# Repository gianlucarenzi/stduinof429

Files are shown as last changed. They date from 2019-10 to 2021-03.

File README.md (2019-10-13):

# STDuinoF429
=====================================

First attempt to have an ARDUINO (STM32 Based) Board for usage in 8-bit micros
like Atari 400/800/800XL/130XE and Commodore 64

# Rendered Images
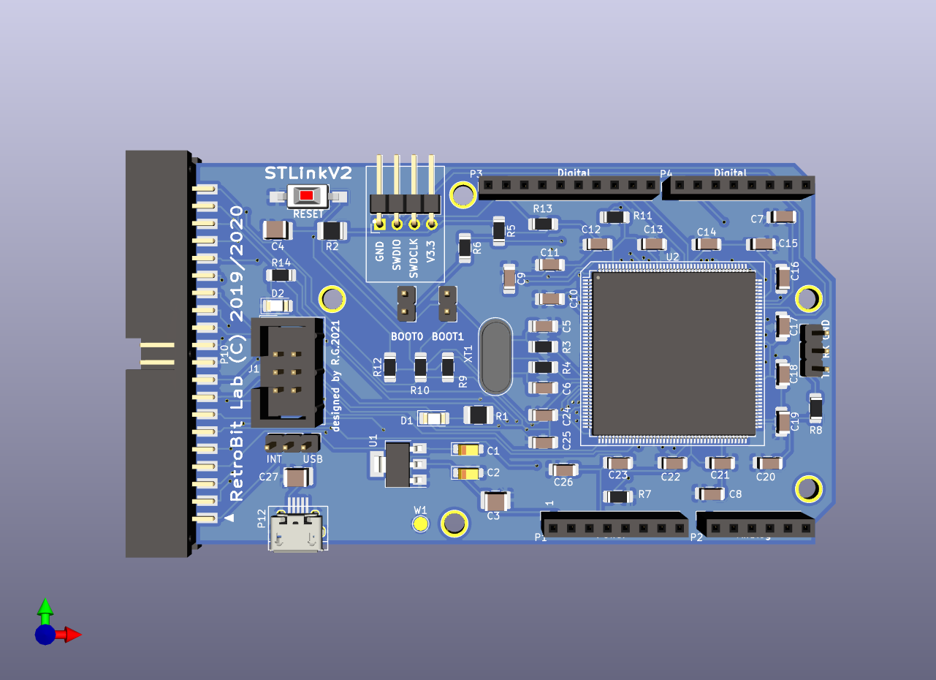
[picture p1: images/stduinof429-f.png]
Board Front
# 
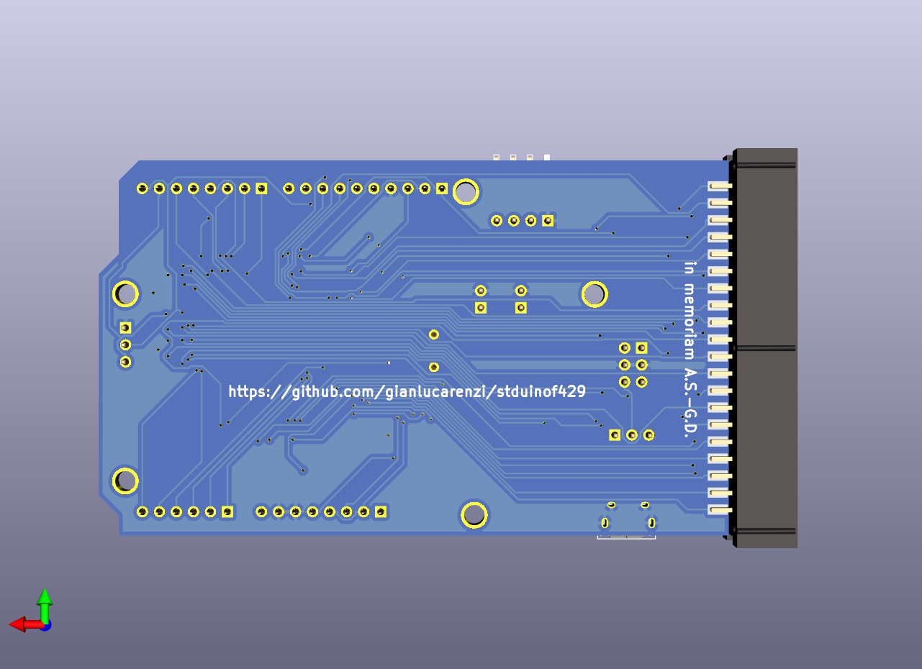
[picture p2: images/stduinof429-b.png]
Board Back
# 
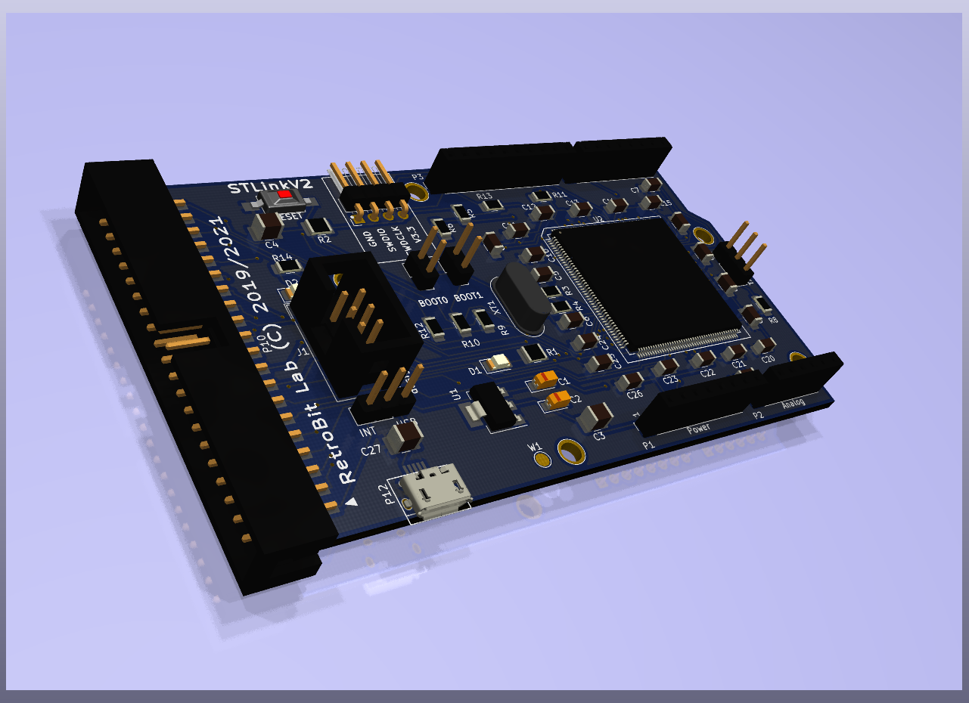
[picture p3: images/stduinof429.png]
Board Overall
# 

Hardware License
---------------------------
Copyright (C) 2018/2019 Gianluca Renzi <gianlucarenzi@eurek.it> <icjtqr@gmail.com>

The hardware of this project is released as free/open hardware under the
GNU GPL v3 License terms. See LICENSE for details.

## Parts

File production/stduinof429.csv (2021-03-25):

Id | Designator | Package | Quantity | Designation | Supplier and ref
1 | P10 | IDC_02X20_2.54mm_Horizontal_PCB_2SIDES | 1 | Conn_02x20_Odd_Even
2 | XT1 | Crystal_HC49-4H_Vertical_3D | 1 | 8Mhz
3 | SW1 | SW_SPST_FSMSM_3D | 1 | SW_PUSH
4 | P12 | USB_Micro-B_Large_Pads | 1 | USB_OTG
5 | J1 | IDC-Header_2x03_P2.54mm_Vertical | 1 | Conn_02x03_Odd_Even
6 | U1 | SOT-223 | 1 | AZ1117-3.3
7 | C7,C8 | C_1206_3216Metric_Pad1.42x1.75mm_HandSolder | 2 | 2.2u
8 | C21,C11,C12,C13,C14,C15,C16,C17,C18,C19,C9,C26,C25,C24,C23,C22,C20 | C_1206_3216Metric_Pad1.42x1.75mm_HandSolder | 17 | 100n
9 | C6,C5 | C_1206_3216Metric_Pad1.42x1.75mm_HandSolder | 2 | 20p
10 | C10 | C_1206_3216Metric_Pad1.42x1.75mm_HandSolder | 1 | 1u
11 | C3,C4,C27 | C_1210_3225Metric_Pad1.42x2.65mm_HandSolder | 3 | 100n
12 | C2 | CP_EIA-3216-18_Kemet-A_Pad1.58x1.35mm_HandSolder | 1 | 22u
13 | C1 | CP_EIA-3216-18_Kemet-A_Pad1.58x1.35mm_HandSolder | 1 | 10u
14 | BOOT0_MEM1,BOOT1_MEM1 | PinHeader_1x02_P2.54mm_Vertical | 2 | CONN_01X02
15 | DEBUG1,P11 | PinHeader_1x03_P2.54mm_Vertical | 2 | CONN_01X03
16 | SWDIO/CLK1 | PinHeader_1x04_P2.54mm_Horizontal | 1 | CONN_01X04
17 | P2 | PinSocket_1x06_P2.54mm_Vertical | 1 | Analog
18 | P1 | PinSocket_1x08_P2.54mm_Vertical | 1 | Power
19 | P4 | PinSocket_1x08_P2.54mm_Vertical | 1 | Digital
20 | P3 | PinSocket_1x10_P2.54mm_Vertical | 1 | Digital
21 | D2 | LED_1206_3216Metric_Pad1.42x1.75mm_HandSolder | 1 | LED.GREEN
22 | D1 | LED_1206_3216Metric_Pad1.42x1.75mm_HandSolder | 1 | LED
23 | U2 | LQFP-176_24x24mm_P0.5mm | 1 | STM32F429IGTx
24 | R9,R5,R8,R11 | R_1206_3216Metric_Pad1.42x1.75mm_HandSolder | 4 | 10K
25 | R4 | R_1206_3216Metric_Pad1.42x1.75mm_HandSolder | 1 | 220
26 | R6,R10 | R_1206_3216Metric_Pad1.42x1.75mm_HandSolder | 2 | 510
27 | R7,R3 | R_1206_3216Metric_Pad1.42x1.75mm_HandSolder | 2 | 0
28 | R12,R13 | R_1206_3216Metric_Pad1.42x1.75mm_HandSolder | 2 | 4.7K
29 | R14 | R_1206_3216Metric_Pad1.42x1.75mm_HandSolder | 1 | 330
30 | R2 | R_1210_3225Metric_Pad1.42x2.65mm_HandSolder | 1 | 22K
31 | R1 | R_1210_3225Metric_Pad1.42x2.65mm_HandSolder | 1 | 1.5K
32 | W1 | TestPoint_Pad_D2.0mm | 1 | TP1
33 | P5,P6,P7,P8,P9 | MountingHole | 5 | CONN_1

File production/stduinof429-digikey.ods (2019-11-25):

Indice | Quantità | Codice componente | Codice produttore | Descrizione | Riferimento cliente | Disponibile | Ordine arretrato | Prezzo unitario | Prezzo totale EUR
1 | 1 | 497-17455-ND | STM32F429IGT6 | IC MCU 32BIT 1MB FLASH 176LQFP | U2 | 1 | 0 | 1,228,000 | 1,228
2 | 1 | 478-1657-1-ND | TAJA106M010RNJ | CAP TANT 10UF 20% 10V 1206 | C1 | 1 | 0 | 36,000 | 36
3 | 1 | 399-3692-1-ND | T491A226M010AT | CAP TANT 22UF 20% 10V 1206 | C2 | 1 | 0 | 66,000 | 66
4 | 3 | 399-15596-1-ND | C1210C104K3RAC7800 | CAP CER 0.1UF 25V X7R 1210 | C3, C4, C27 | 3 | 0 | 55,000 | 165
5 | 2 | 311-1153-1-ND | CC1206JRNPO9BN200 | CAP CER 20PF 50V C0G/NPO 1206 | C5, C6 | 2 | 0 | 26,000 | 52
6 | 2 | 311-1960-1-ND | CC1206KKX7R8BB225 | CAP CER 2.2UF 25V X7R 1206 | C7, C8 | 2 | 0 | 32,000 | 64
7 | 17 | 720-1803-1-ND | VJ1206Y104KXJPW1BC | CAP CER 0.1UF 16V X7R 1206 | C9,C11,C12,C13,C14,C15,C16,C17,C18,C19,C20,C21 | 17 | 0 | 21,600 | 367
8 | 1 | 399-8148-1-ND | C1206C105M3RACTU | CAP CER 1UF 25V X7R 1206 | C10 | 1 | 0 | 17,000 | 17
9 | 1 | 160-1166-1-ND | LTST-C150AKT | LED AMBER CLEAR SMD | D1 | 1 | 0 | 32,000 | 32
10 | 1 | 160-1643-1-ND | LTST-C150TBKT | LED BLUE CLEAR 1206 SMD | D2 | 1 | 0 | 49,000 | 49
11 | 1 | P1.5KECT-ND | ERJ-8GEYJ152V | RES SMD 1.5K OHM 5% 1/4W 1206 | R1 | 1 | 0 | 9,000 | 9
12 | 1 | RMCF1206JT22K0CT-ND | RMCF1206JT22K0 | RES 22K OHM 5% 1/4W 1206 | R2 | 1 | 0 | 9,000 | 9
13 | 4 | 541-4201-1-ND | CRCW120610K0JNEAC | RES SMD 10K OHM 5% 1/4W 1206 | R9, R11, R5, R8 | 4 | 0 | 9,000 | 36
14 | 2 | RMCF1206JT510RCT-ND | RMCF1206JT510R | RES 510 OHM 5% 1/4W 1206 | R10, R6 | 2 | 0 | 9,000 | 18
15 | 2 | RMCF1206JT4K70CT-ND | RMCF1206JT4K70 | RES 4.7K OHM 5% 1/4W 1206 | R12, R13 | 2 | 0 | 9,000 | 18
16 | 1 | RMCF1206JT330RCT-ND | RMCF1206JT330R | RES 330 OHM 5% 1/4W 1206 | R14 | 1 | 0 | 9,000 | 9
17 | 1 | 450-1140-ND | FSMSM | SWITCH TACTILE SPST-NO 0.05A 24V | SW1 | 1 | 0 | 25,000 | 25
18 | 1 | LM1117MP-3.3/NOPBCT-ND | LM1117MP-3.3/NOPB | IC REG LINEAR 3.3V 800MA SOT223 | U1 | 1 | 0 | 100,000 | 100
19 | 1 | 631-1100-ND | FC4STCBMF8.0-BAG200 | CRYSTAL 8.0000MHZ 20PF T/H | XT1 | 1 | 0 | 32,000 | 32
20 | 2 | RMCF1206ZT0R00CT-ND | RMCF1206ZT0R00 | RES 0 OHM JUMPER 1/4W 1206 | R3, R7 | 2 | 0 | 9,000 | 18
21 | 1 | RMCF1206JT220RCT-ND | RMCF1206JT220R | RES 220 OHM 5% 1/4W 1206 | R4 | 1 | 0 | 9,000 | 9
22 | 1 | 609-4616-1-ND | 10118193-0001LF | CONN RCPT USB2.0 MICRO B SMD R/A | P12 | 1 | 0 | 39,000 | 39
23 | 1 | S9175-ND | SBH11-PBPC-D20-ST-BK | CONN HEADER VERT 40POS 2.54MM | P10 | 1 | 0 | 65,000 | 65
24 | 1 | 1212-1215-ND | 801-87-036-10-005101 | CONN SOCKET 36POS 0.1 GOLD PCB | P1,P2,P3,P4 |  |  |  | 2463

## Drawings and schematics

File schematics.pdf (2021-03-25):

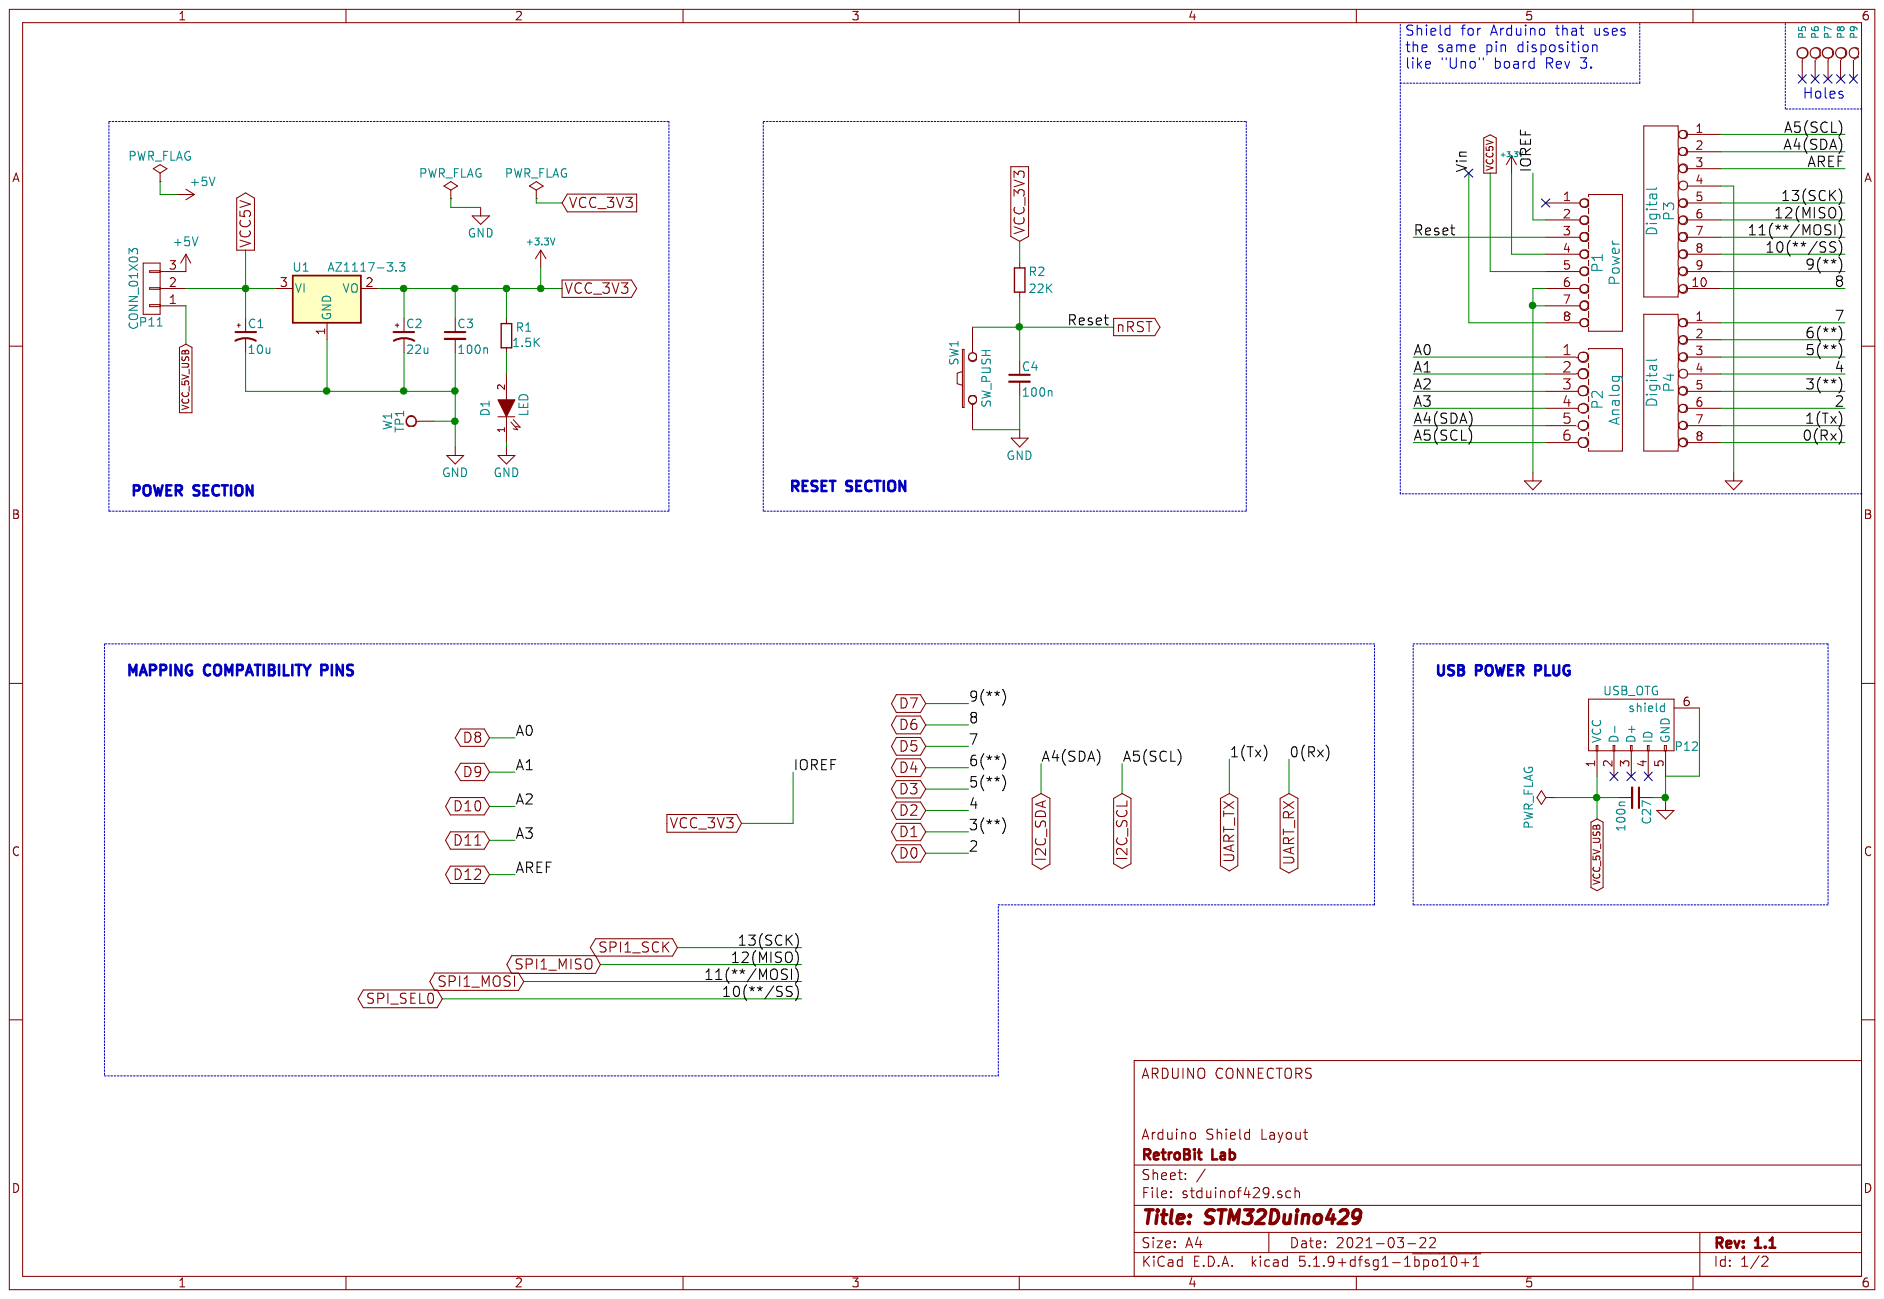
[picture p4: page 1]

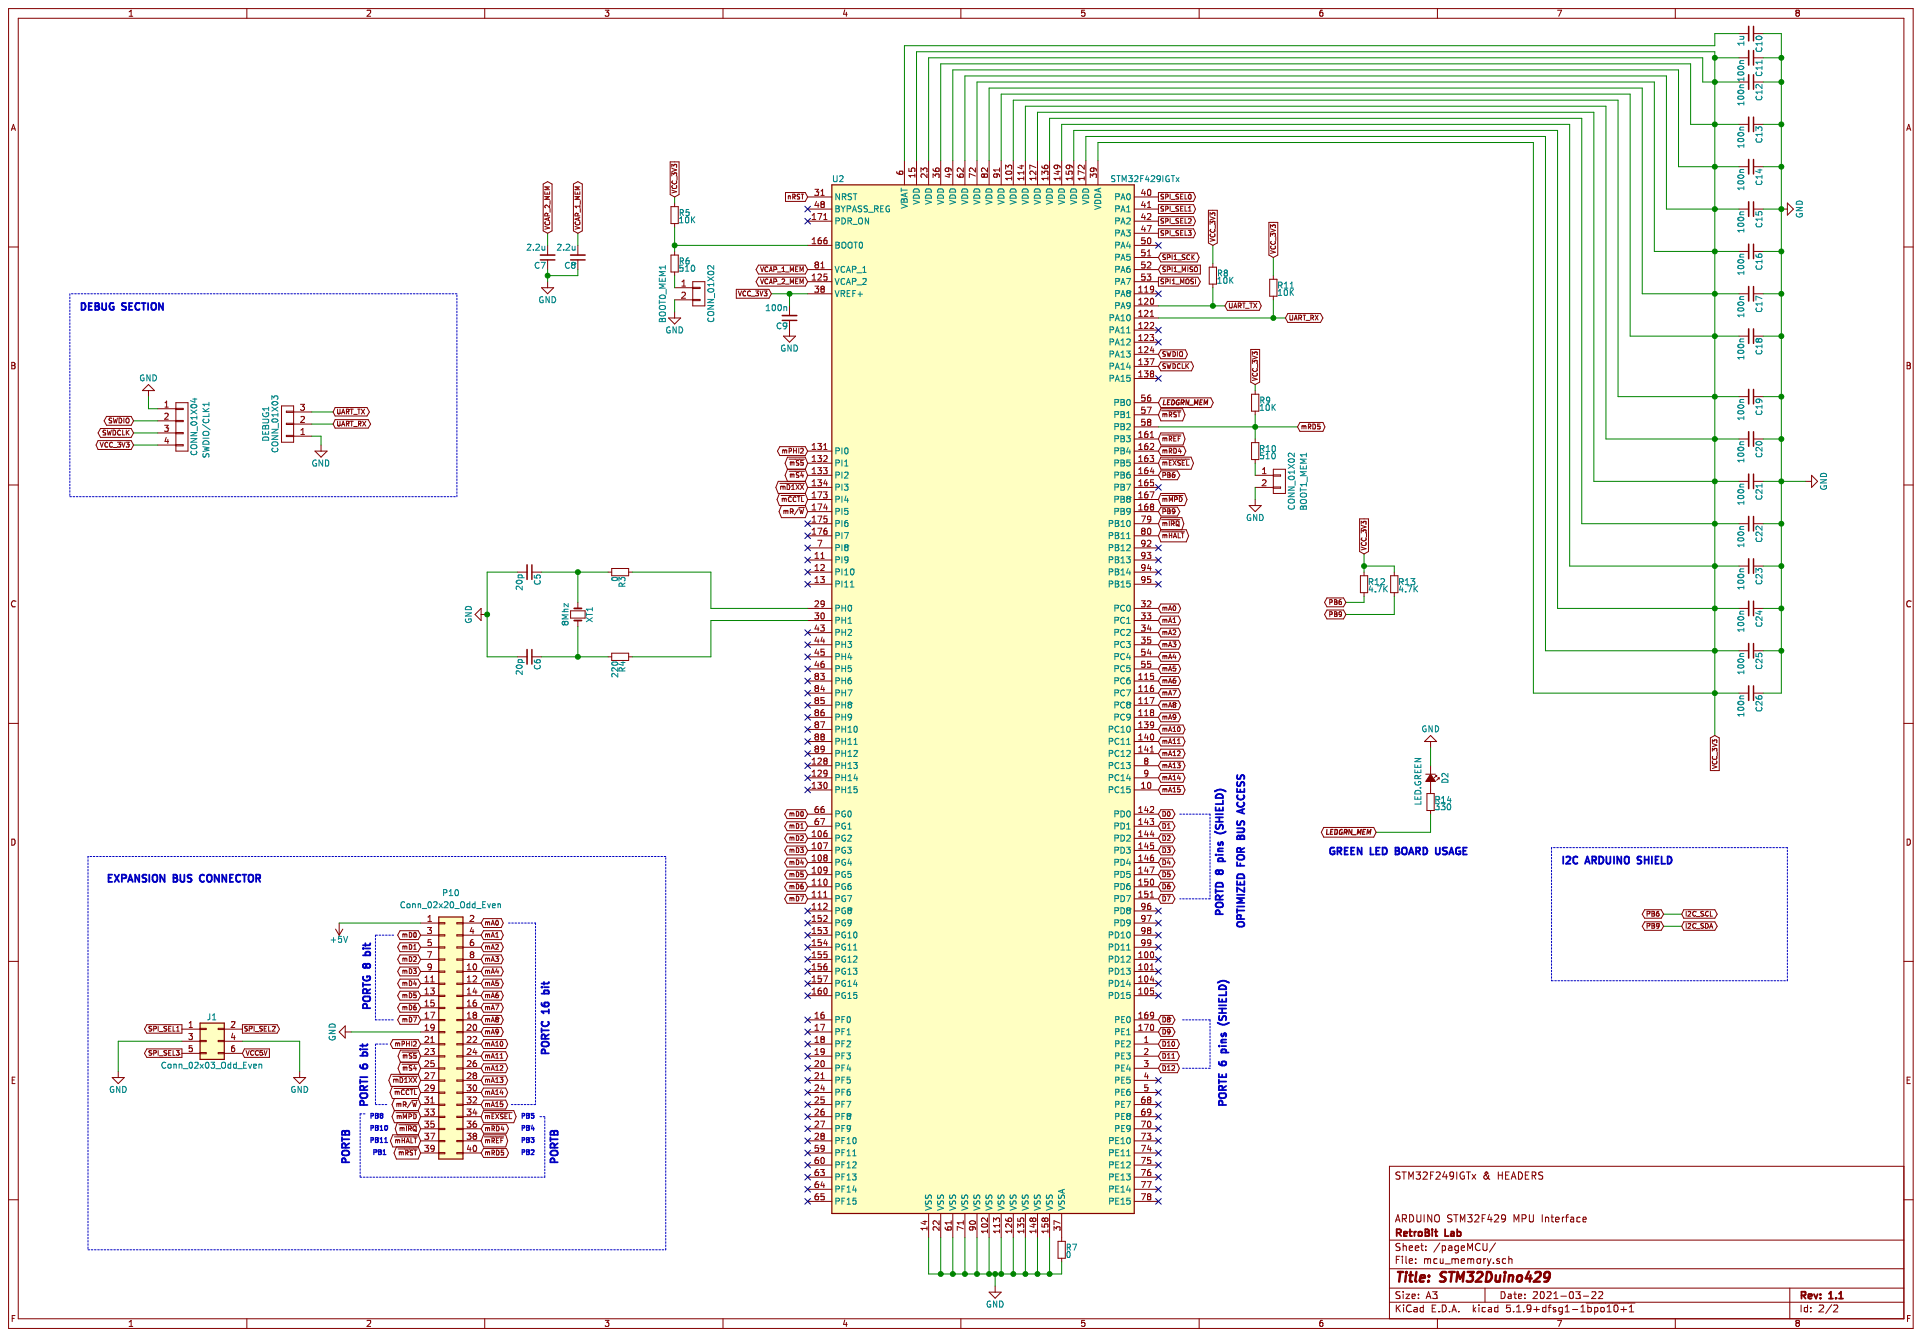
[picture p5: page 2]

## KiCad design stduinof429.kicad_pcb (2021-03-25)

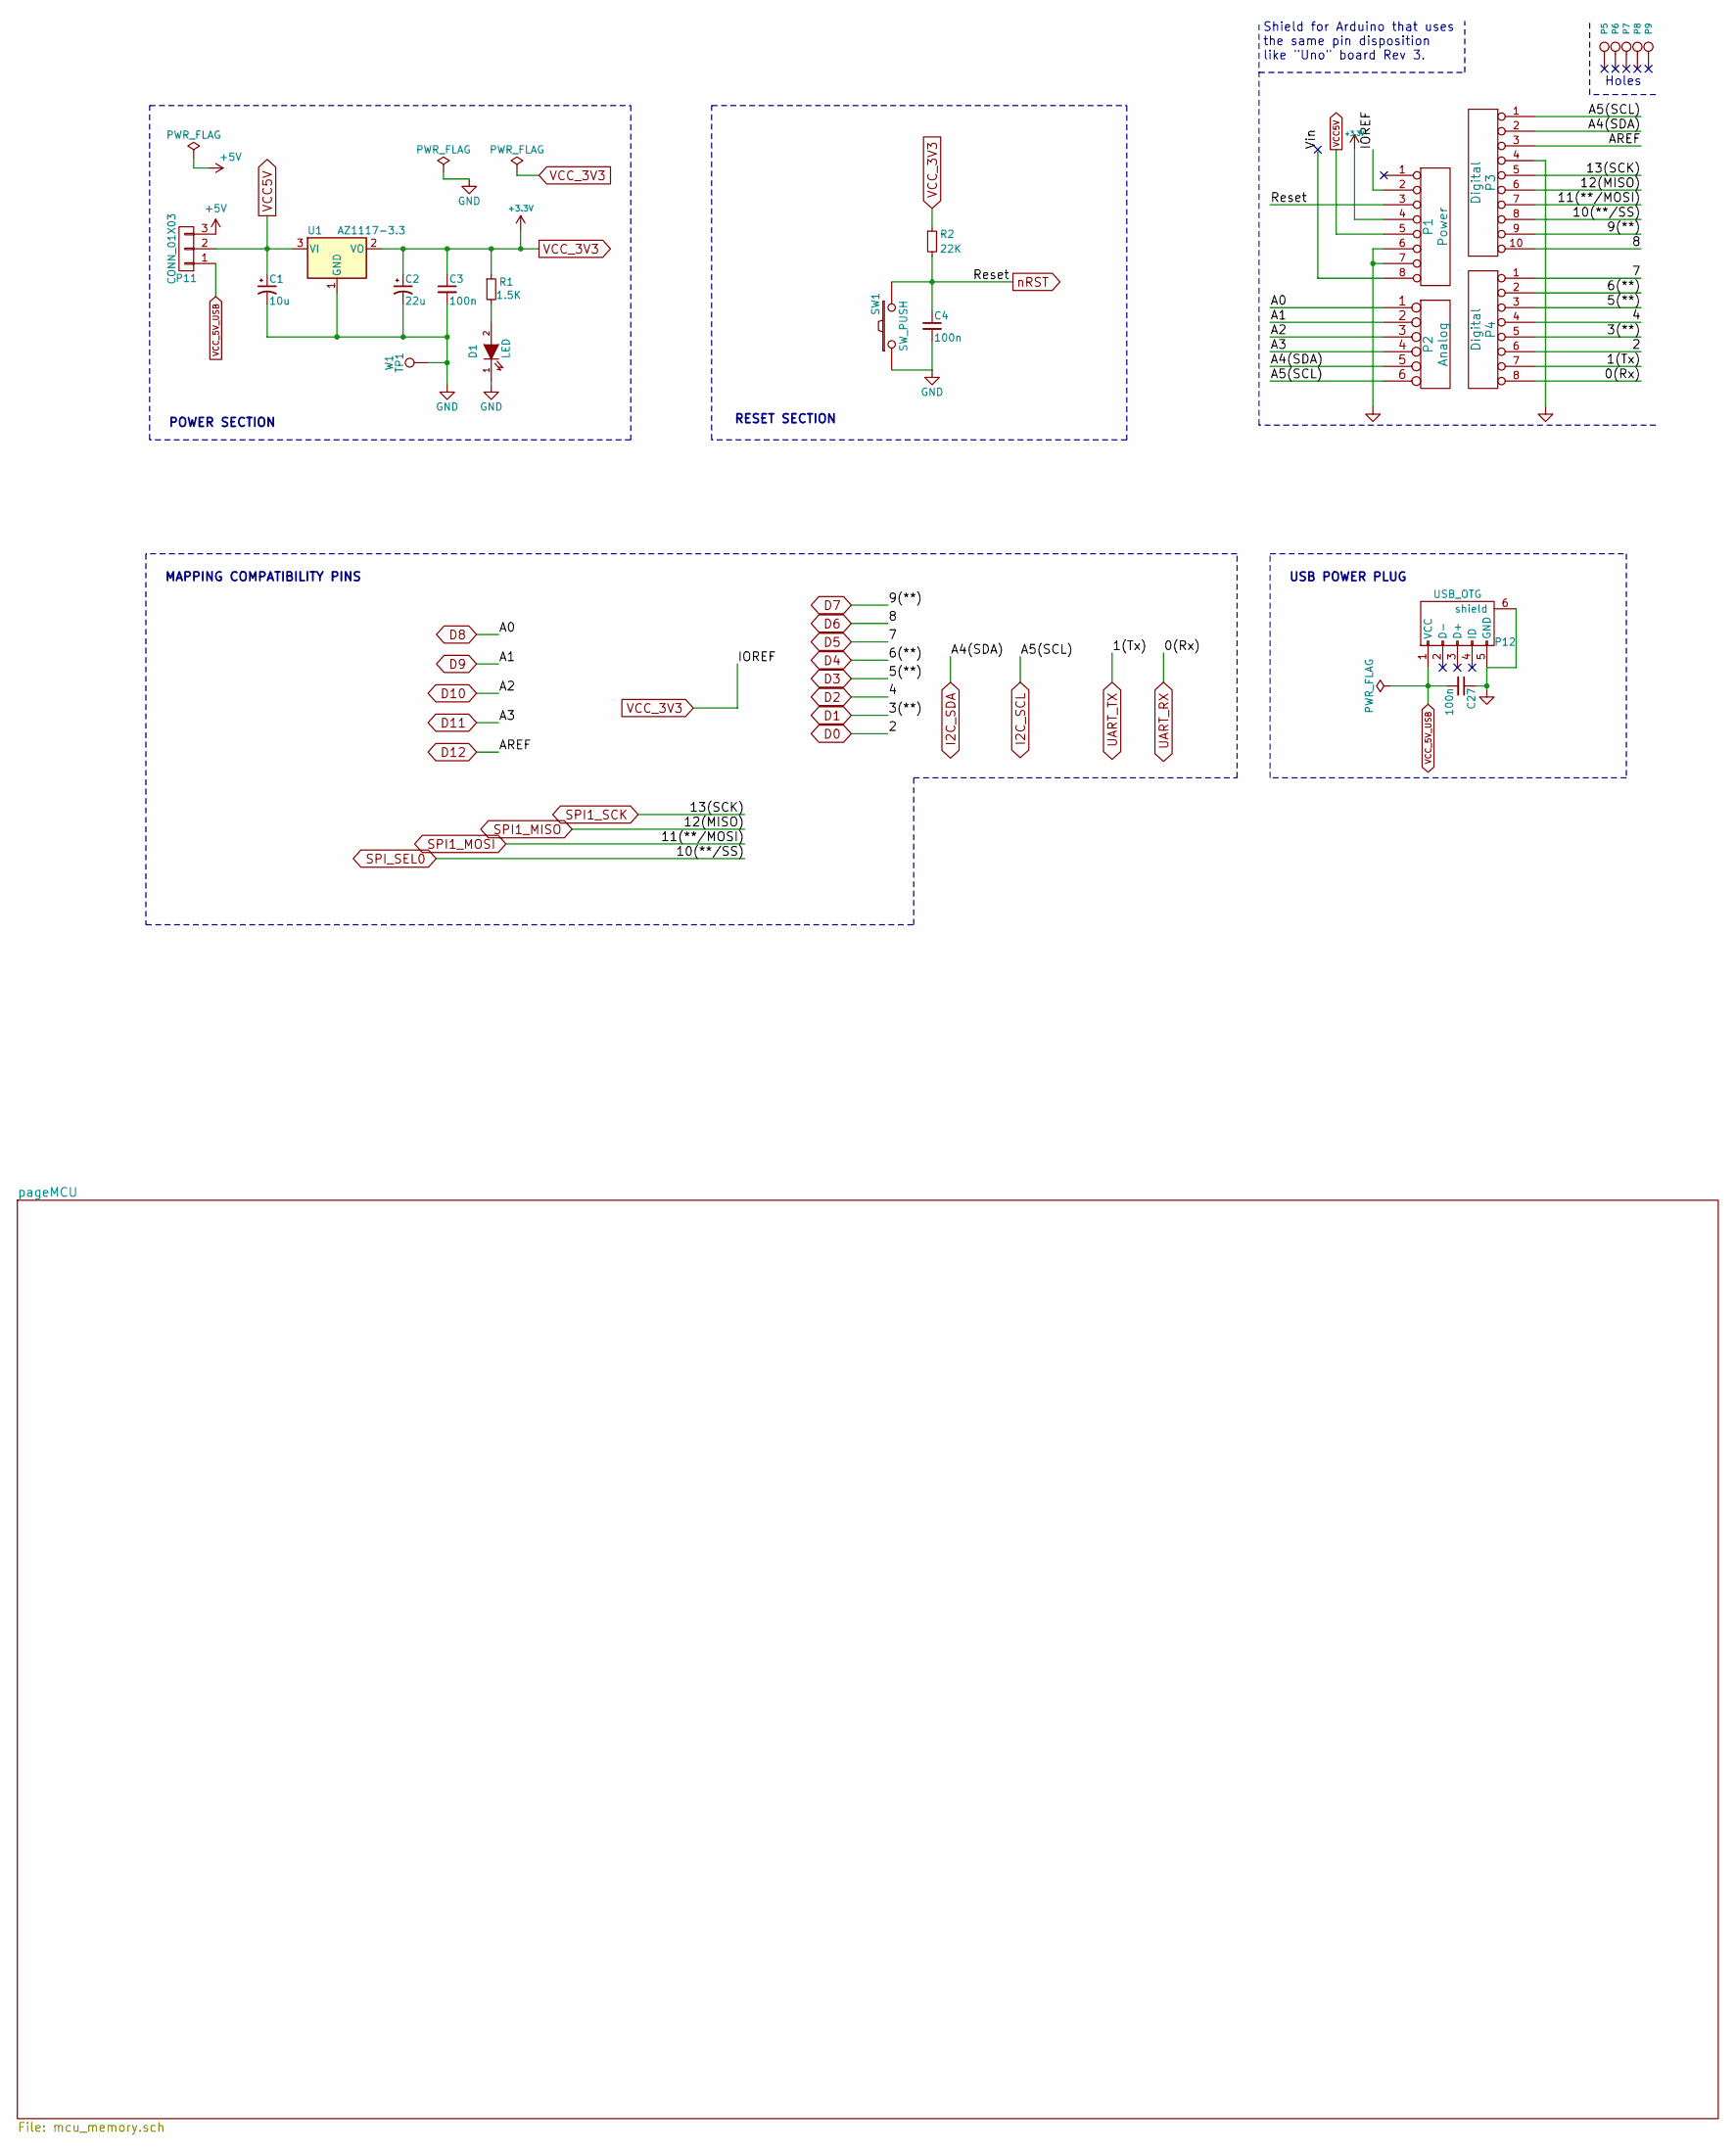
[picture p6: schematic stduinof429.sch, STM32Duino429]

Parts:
C1: 10u; CP_EIA-3216-18_Kemet-A_Pad1.58x1.35mm_HandSolder
C2: 22u; CP_EIA-3216-18_Kemet-A_Pad1.58x1.35mm_HandSolder
C3, C4, C27: 100n; C_1210_3225Metric_Pad1.42x2.65mm_HandSolder
D1: LED; LED_1206_3216Metric_Pad1.42x1.75mm_HandSolder
P1: Power; PinSocket_1x08_P2.54mm_Vertical
P2: Analog; PinSocket_1x06_P2.54mm_Vertical
P3: Digital; PinSocket_1x10_P2.54mm_Vertical
P4: Digital; PinSocket_1x08_P2.54mm_Vertical
P5, P6, P7, P8, P9: CONN_1; MountingHole
P11: CONN_01X03; PinHeader_1x03_P2.54mm_Vertical
P12: USB_OTG; USB_Micro-B_Large_Pads
R1: 1.5K; R_1210_3225Metric_Pad1.42x2.65mm_HandSolder
R2: 22K; R_1210_3225Metric_Pad1.42x2.65mm_HandSolder
SW1: SW_PUSH; SW_SPST_FSMSM_3D
U1: AZ1117-3.3; SOT-223
W1: TP1; TestPoint_Pad_D2.0mm

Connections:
+5V: P11.3; also elsewhere on the board
/Vin: P1.8
D0: P4.6; also elsewhere on the board
D1: P4.5; also elsewhere on the board
D2: P4.4; also elsewhere on the board
D3: P4.3; also elsewhere on the board
D4: P4.2; also elsewhere on the board
D5: P4.1; also elsewhere on the board
D6: P3.10; also elsewhere on the board
D7: P3.9; also elsewhere on the board
D8: P2.1; also elsewhere on the board
D9: P2.2; also elsewhere on the board
D10: P2.3; also elsewhere on the board
D11: P2.4; also elsewhere on the board
D12: P3.3; also elsewhere on the board
GND: C1.2, C2.2, C3.2, C4.2, C27.1, D1.1 (K), P1.6, P1.7, P3.4, P12.5 (GND), P12.6 (shield), SW1.1, U1.1 (GND), W1.1; also elsewhere on the board
I2C_SCL: P2.6, P3.1; also elsewhere on the board
I2C_SDA: P2.5, P3.2; also elsewhere on the board
unnamed: D1.2 (A), R1.2
SPI1_MISO: P3.6; also elsewhere on the board
SPI1_MOSI: P3.7; also elsewhere on the board
SPI1_SCK: P3.5; also elsewhere on the board
SPI_SEL0: P3.8; also elsewhere on the board
UART_RX: P4.8; also elsewhere on the board
UART_TX: P4.7; also elsewhere on the board
VCC5V: C1.1, P1.5, P11.2, U1.3 (VI); also elsewhere on the board
VCC_3V3: C2.1, C3.1, P1.2, P1.4, R1.1, R2.1, U1.2 (VO); also elsewhere on the board
VCC_5V_USB: C27.2, P11.1, P12.1 (VCC)
nRST: C4.1, P1.3, R2.2, SW1.2; also elsewhere on the board

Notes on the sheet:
Holes
Shield for Arduino that uses the same pin disposition like "Uno" board Rev 3.
POWER SECTION
MAPPING COMPATIBILITY PINS
RESET SECTION
USB POWER PLUG

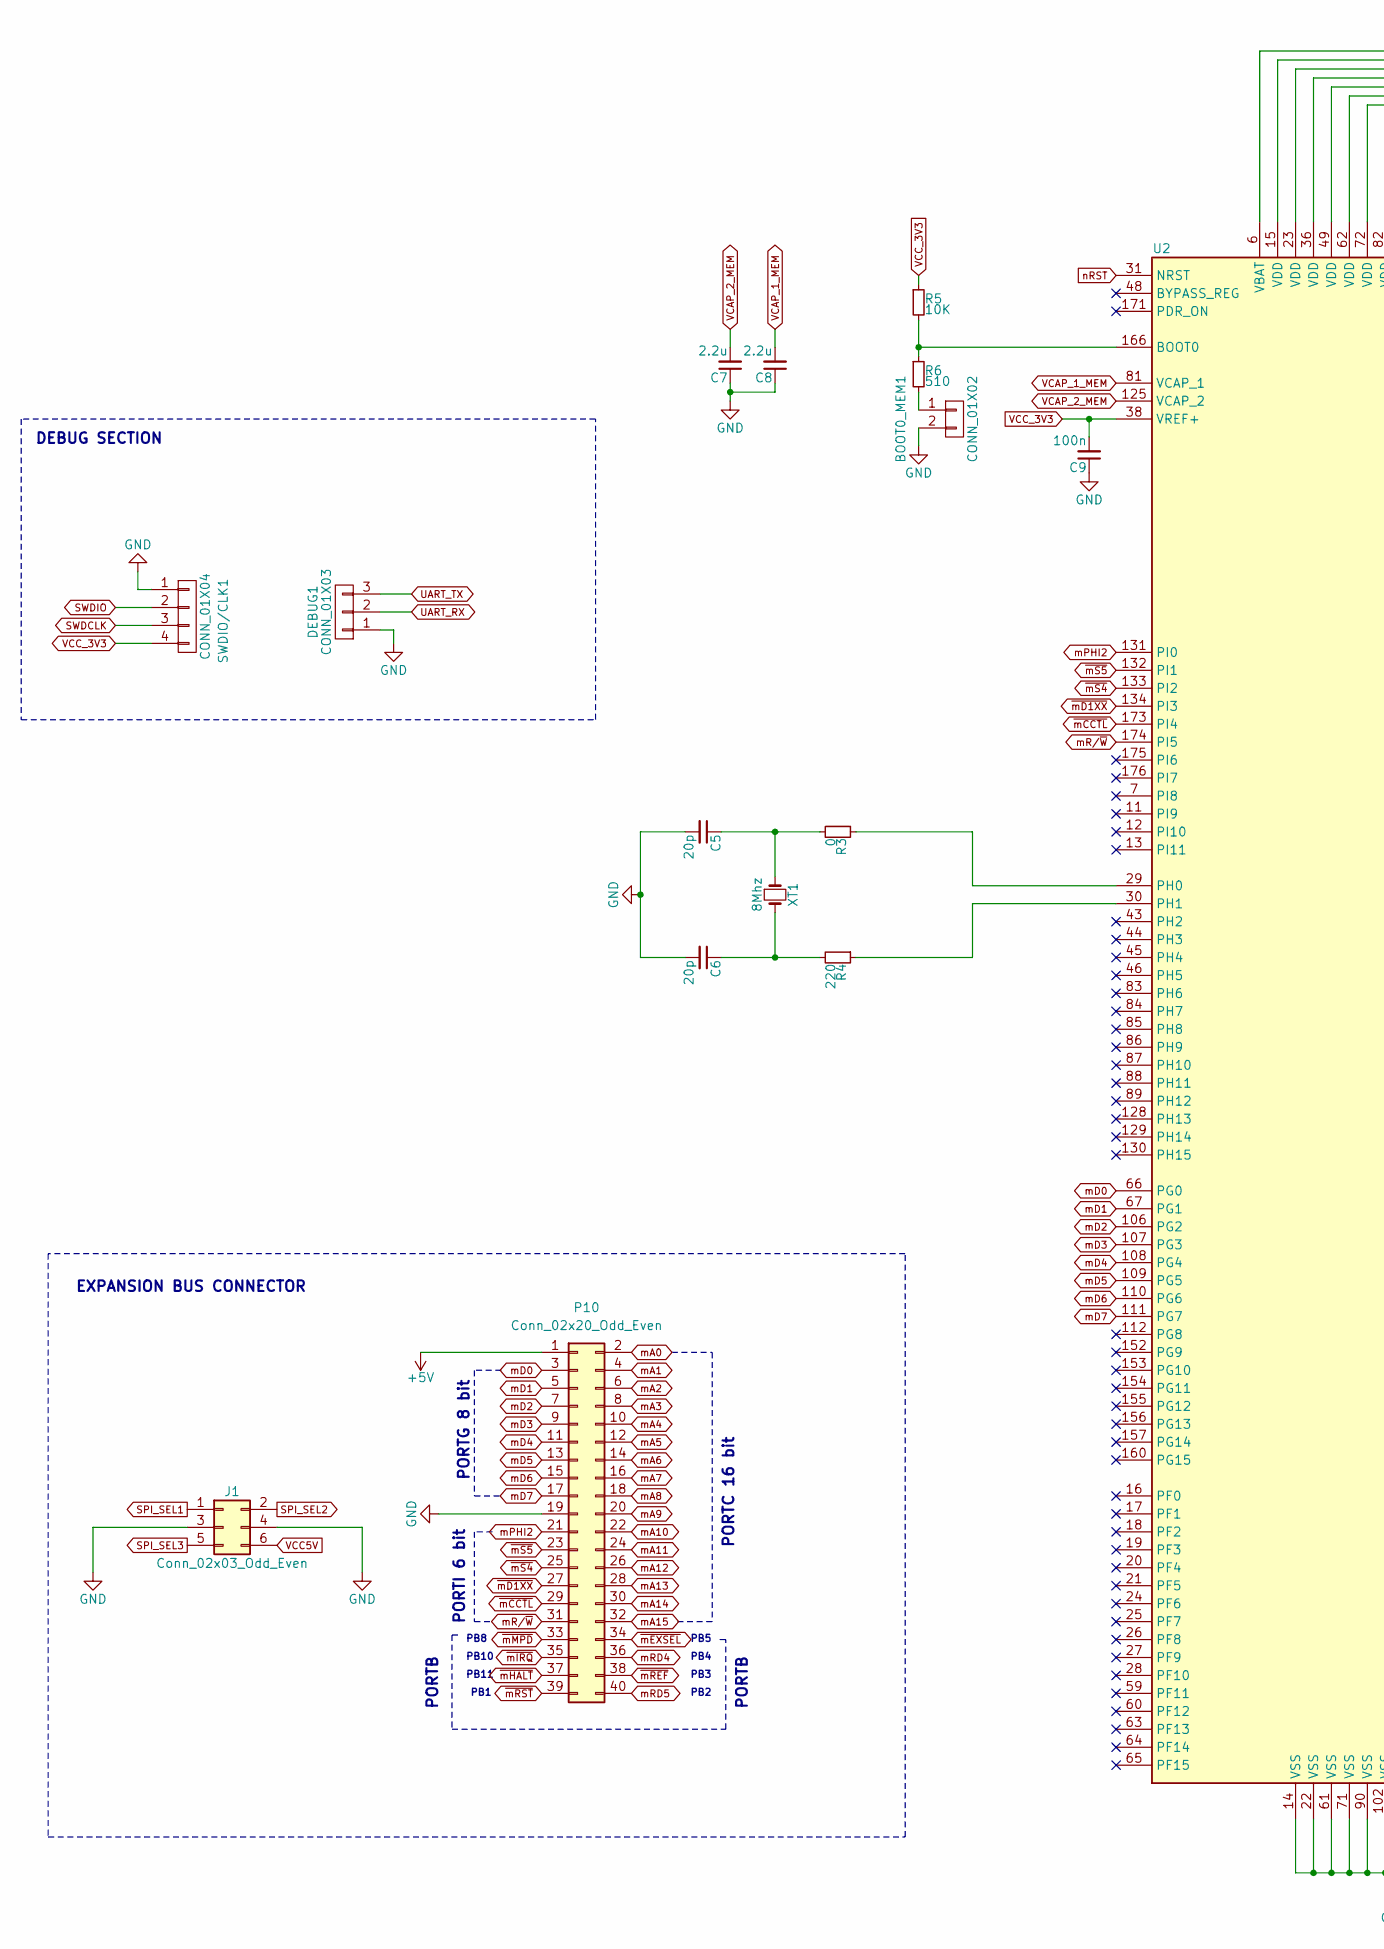
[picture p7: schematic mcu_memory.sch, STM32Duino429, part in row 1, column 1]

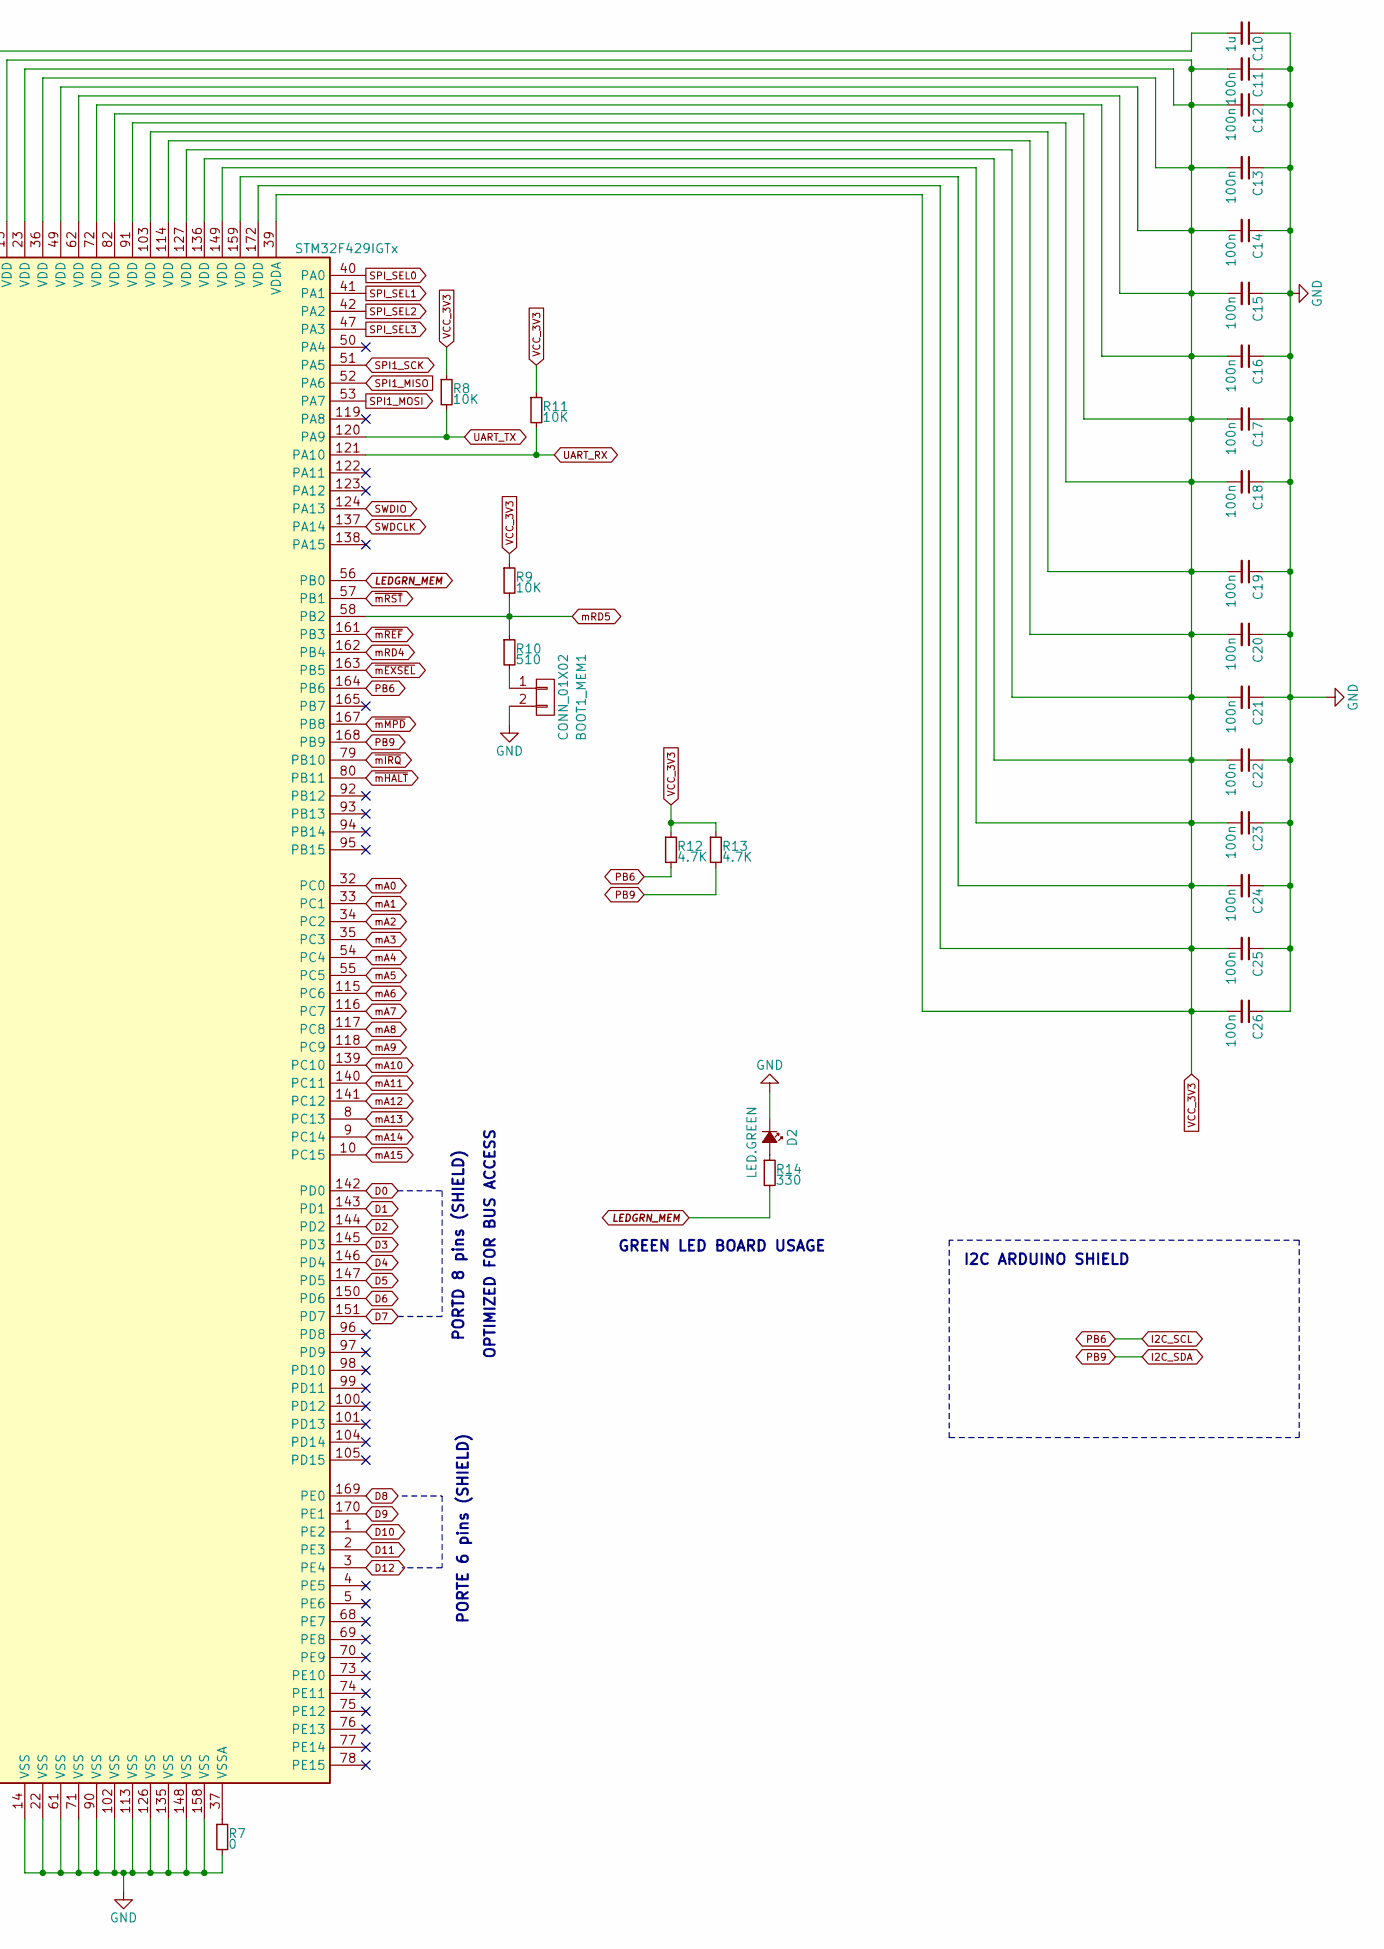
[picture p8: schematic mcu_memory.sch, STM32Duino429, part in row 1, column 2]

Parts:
BOOT0_MEM1, BOOT1_MEM1: CONN_01X02; PinHeader_1x02_P2.54mm_Vertical
C5, C6: 20p; C_1206_3216Metric_Pad1.42x1.75mm_HandSolder
C7, C8: 2.2u; C_1206_3216Metric_Pad1.42x1.75mm_HandSolder
C9, C11, C12, C13, C14, C15, C16, C17, C18, C19, C20, C21, C22, C23, C24, C25, C26: 100n; C_1206_3216Metric_Pad1.42x1.75mm_HandSolder
C10: 1u; C_1206_3216Metric_Pad1.42x1.75mm_HandSolder
D2: LED.GREEN; LED_1206_3216Metric_Pad1.42x1.75mm_HandSolder
DEBUG1: CONN_01X03; PinHeader_1x03_P2.54mm_Vertical
J1: Conn_02x03_Odd_Even; IDC-Header_2x03_P2.54mm_Vertical
P10: Conn_02x20_Odd_Even; IDC_02X20_2.54mm_Horizontal_PCB_2SIDES
R3, R7: 0; R_1206_3216Metric_Pad1.42x1.75mm_HandSolder
R4: 220; R_1206_3216Metric_Pad1.42x1.75mm_HandSolder
R5, R8, R9, R11: 10K; R_1206_3216Metric_Pad1.42x1.75mm_HandSolder
R6, R10: 510; R_1206_3216Metric_Pad1.42x1.75mm_HandSolder
R12, R13: 4.7K; R_1206_3216Metric_Pad1.42x1.75mm_HandSolder
R14: 330; R_1206_3216Metric_Pad1.42x1.75mm_HandSolder
SWDIO/CLK1: CONN_01X04; PinHeader_1x04_P2.54mm_Horizontal
U2: STM32F429IGTx; LQFP-176_24x24mm_P0.5mm
XT1: 8Mhz; Crystal_HC49-4H_Vertical_3D

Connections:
+5V: P10.1; also elsewhere on the board
D0: U2.142 (PD0); also elsewhere on the board
D1: U2.143 (PD1); also elsewhere on the board
D2: U2.144 (PD2); also elsewhere on the board
D3: U2.145 (PD3); also elsewhere on the board
D4: U2.146 (PD4); also elsewhere on the board
D5: U2.147 (PD5); also elsewhere on the board
D6: U2.150 (PD6); also elsewhere on the board
D7: U2.151 (PD7); also elsewhere on the board
D8: U2.169 (PE0); also elsewhere on the board
D9: U2.170 (PE1); also elsewhere on the board
D10: U2.1 (PE2); also elsewhere on the board
D11: U2.2 (PE3); also elsewhere on the board
D12: U2.3 (PE4); also elsewhere on the board
GND: BOOT0_MEM1.2, BOOT1_MEM1.2, C5.2, C6.2, C7.1, C8.1, C9.1, C10.1, C11.1, C12.1, C13.1, C14.1, C15.1, C16.1, C17.1, C18.1, C19.1, C20.1, C21.1, C22.1, C23.1, C24.1, C25.1, C26.1, D2.1 (K), DEBUG1.1, J1.3, J1.4, P10.19, R7.2, SWDIO/CLK1.1, U2.14 (VSS), U2.22 (VSS), U2.61 (VSS), U2.71 (VSS), U2.90 (VSS), U2.102 (VSS), U2.113 (VSS), U2.126 (VSS), U2.135 (VSS), U2.148 (VSS), U2.158 (VSS); also elsewhere on the board
I2C_SCL: R12.2, U2.164 (PB6); also elsewhere on the board
I2C_SDA: R13.2, U2.168 (PB9); also elsewhere on the board
LEDGRN_MEM: R14.2, U2.56 (PB0)
unnamed: BOOT0_MEM1.1, R6.2
unnamed: BOOT1_MEM1.1, R10.2
unnamed: C5.1, R3.2, XT1.1
unnamed: C6.1, R4.2, XT1.2
unnamed: C10.2, U2.6 (VBAT)
unnamed: D2.2 (A), R14.1
unnamed: R3.1, U2.29 (PH0)
unnamed: R4.1, U2.30 (PH1)
unnamed: R5.2, R6.1, U2.166 (BOOT0)
unnamed: R7.1, U2.37 (VSSA)
SPI1_MISO: U2.52 (PA6); also elsewhere on the board
SPI1_MOSI: U2.53 (PA7); also elsewhere on the board
SPI1_SCK: U2.51 (PA5); also elsewhere on the board
SPI_SEL0: U2.40 (PA0); also elsewhere on the board
SPI_SEL1: J1.1, U2.41 (PA1)
SPI_SEL2: J1.2, U2.42 (PA2)
SPI_SEL3: J1.5, U2.47 (PA3)
SWDCLK: SWDIO/CLK1.3, U2.137 (PA14)
SWDIO: SWDIO/CLK1.2, U2.124 (PA13)
UART_RX: DEBUG1.2, R11.2, U2.121 (PA10); also elsewhere on the board
UART_TX: DEBUG1.3, R8.2, U2.120 (PA9); also elsewhere on the board
VCAP_1_MEM: C8.2, U2.81 (VCAP_1)
VCAP_2_MEM: C7.2, U2.125 (VCAP_2)
VCC5V: J1.6; also elsewhere on the board
VCC_3V3: C9.2, C11.2, C12.2, C13.2, C14.2, C15.2, C16.2, C17.2, C18.2, C19.2, C20.2, C21.2, C22.2, C23.2, C24.2, C25.2, C26.2, R5.1, R8.1, R9.1, R11.1, R12.1, R13.1, SWDIO/CLK1.4, U2.15 (VDD), U2.23 (VDD), U2.36 (VDD), U2.38 (VREF+), U2.39 (VDDA), U2.49 (VDD), U2.62 (VDD), U2.72 (VDD), U2.82 (VDD), U2.91 (VDD), U2.103 (VDD), U2.114 (VDD), U2.127 (VDD), U2.136 (VDD), U2.149 (VDD), U2.159 (VDD), U2.172 (VDD); also elsewhere on the board
mA0: P10.2, U2.32 (PC0)
mA1: P10.4, U2.33 (PC1)
mA2: P10.6, U2.34 (PC2)
mA3: P10.8, U2.35 (PC3)
mA4: P10.10, U2.54 (PC4)
mA5: P10.12, U2.55 (PC5)
mA6: P10.14, U2.115 (PC6)
mA7: P10.16, U2.116 (PC7)
mA8: P10.18, U2.117 (PC8)
mA9: P10.20, U2.118 (PC9)
mA10: P10.22, U2.139 (PC10)
mA11: P10.24, U2.140 (PC11)
mA12: P10.26, U2.141 (PC12)
mA13: P10.28, U2.8 (PC13)
mA14: P10.30, U2.9 (PC14)
mA15: P10.32, U2.10 (PC15)
mD0: P10.3, U2.66 (PG0)
mD1: P10.5, U2.67 (PG1)
mD2: P10.7, U2.106 (PG2)
mD3: P10.9, U2.107 (PG3)
mD4: P10.11, U2.108 (PG4)
mD5: P10.13, U2.109 (PG5)
mD6: P10.15, U2.110 (PG6)
mD7: P10.17, U2.111 (PG7)
mPHI2: P10.21, U2.131 (PI0)
mR/~W: P10.31, U2.174 (PI5)
mRD4: P10.36, U2.162 (PB4)
mRD5: P10.40, R9.2, R10.1, U2.58 (PB2)
nRST: U2.31 (NRST); also elsewhere on the board
~mCCTL: P10.29, U2.173 (PI4)
~mD1XX: P10.27, U2.134 (PI3)
~mEXSEL: P10.34, U2.163 (PB5)
~mHALT: P10.37, U2.80 (PB11)
~mIRQ: P10.35, U2.79 (PB10)
~mMPD: P10.33, U2.167 (PB8)
~mREF: P10.38, U2.161 (PB3)
~mRST: P10.39, U2.57 (PB1)
~mS4: P10.25, U2.133 (PI2)
~mS5: P10.23, U2.132 (PI1)

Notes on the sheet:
GREEN LED BOARD USAGE
DEBUG SECTION
EXPANSION BUS CONNECTOR
I2C ARDUINO SHIELD
PORTC 16 bit
PORTG 8 bit
PORTD 8 pins (SHIELD)
PORTI 6 bit
PB8
PB10
PB11
PB1
PB2
PB3
PB4
PB5
PORTB
PORTE 6 pins (SHIELD)
OPTIMIZED FOR BUS ACCESS

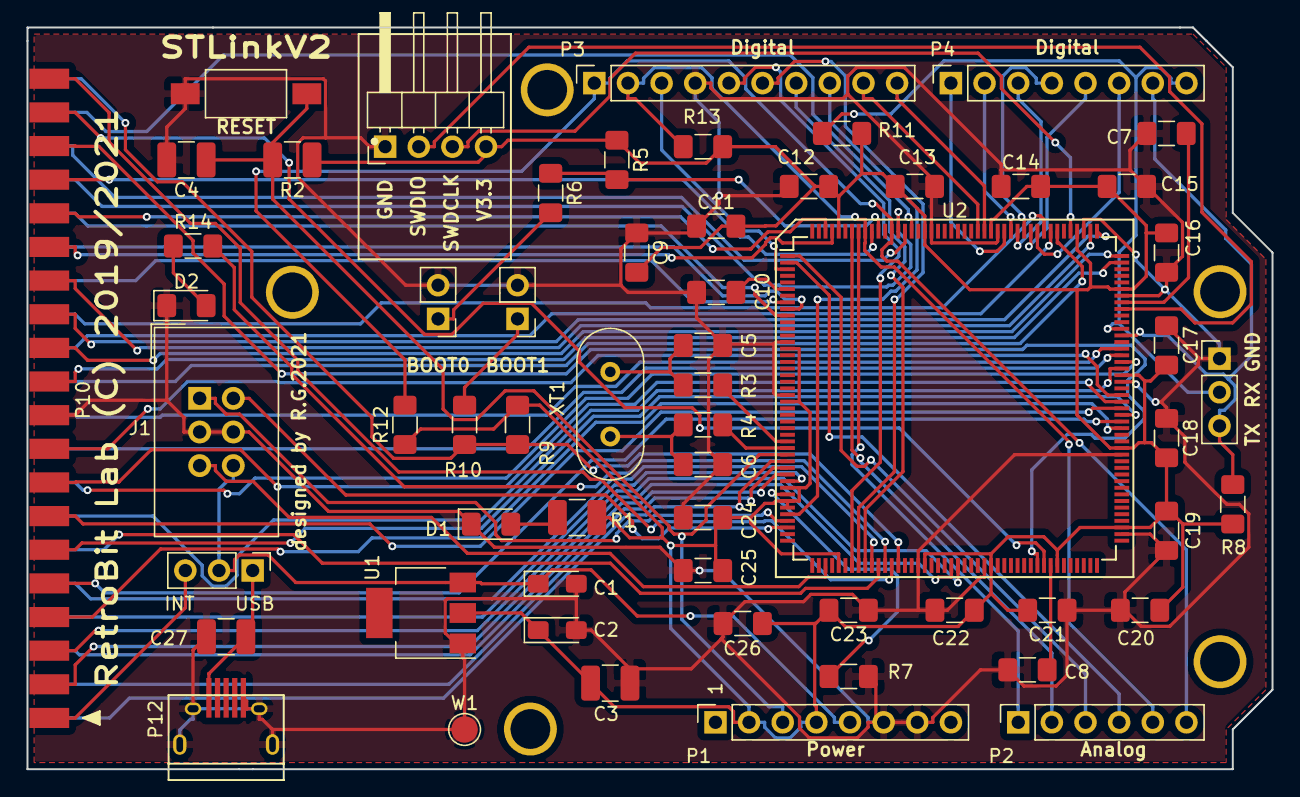
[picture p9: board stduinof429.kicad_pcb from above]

Board: 2 copper layers, 94.0 x 56.0 mm, 65 parts (0 on the bottom side), 84 nets.

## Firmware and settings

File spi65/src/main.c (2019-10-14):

/**
  ******************************************************************************
  * @file           : main.c
  * @brief          : Main program body
  ******************************************************************************
  * @attention
  *
  * <h2><center>&copy; Copyright (c) 2019 STMicroelectronics.
  * All rights reserved.</center></h2>
  *
  * This software component is licensed by ST under BSD 3-Clause license,
  * the "License"; You may not use this file except in compliance with the
  * License. You may obtain a copy of the License at:
  *                        opensource.org/licenses/BSD-3-Clause
  *
  ******************************************************************************
  *   *
  */

#include <stdio.h>
#include <string.h>
#include "syscall.h"
#include "debug.h"
#include "main.h"

#define CONTROL_IN  GPIOI->IDR
#define ADDR_IN     GPIOC->IDR
#define DATA_IN     GPIOG->IDR
#define DATA_OUT    GPIOG->ODR

#define PHI2_RD        (GPIOI->IDR & 0x0001)
#define S5_RD          (GPIOI->IDR & 0x0002)
#define S4_RD          (GPIOI->IDR & 0x0004)
#define S4_AND_S5_HIGH (GPIOI->IDR & 0x0006) == 0x6
#define D1XX_RD        (GPIOI->IDR & 0x0008)

#define PHI2    0x0001
#define S5      0x0002
#define S4      0x0004
#define D1XX    0x0008
#define CCTL    0x0010
#define RW      0x0020

#define SET_DATA_MODE_IN        GPIOG->MODER = 0x00000000;
#define SET_DATA_MODE_OUT       GPIOG->MODER = 0x00005555;

#define GREEN_LED_OFF           LL_GPIO_ResetOutputPin(GPIOB, GPIO_PIN_0);  /* HIGH ACTIVE */
#define GREEN_LED_ON            LL_GPIO_SetOutputPin(GPIOB, GPIO_PIN_0);    /* HIGH ACTIVE */

#define CPU_RESET_ASSERT      LL_GPIO_ResetOutputPin(GPIOB, GPIO_PIN_1); /* RST -> GPIO(B.1) LOW */
#define CPU_RESET_DEASSERT    LL_GPIO_SetOutputPin(GPIOB, GPIO_PIN_1);   /* RST -> GPIO(B.1) HIGH */

#define SPI_SLAVE_SELECT(a)   LL_GPIO_ResetOutputPin(GPIOA, (1 << a)); /* PA0-PA1-PA2-PA3 */

static volatile uint8_t SPI_DATA_IN;
static volatile uint8_t SPI_DATA_OUT;
static volatile uint8_t SPI_STATUS_REGISTER;
static volatile uint8_t SPI_CONTROL_REGISTER;
static volatile uint8_t SPI_CLK_DIVISOR_REGISTER;
static volatile uint8_t SPI_SLAVE_SELECT_REGISTER;
static volatile uint32_t spi_prescaler = 0;
static volatile uint32_t spi_cpol = 0;
static volatile uint32_t spi_cpha = 0;
static volatile uint32_t spi_csel = 0;
static volatile int SPI_ENABLED = 0;

#define ATARI_PBI_DEVICE
#undef  ATARI_PBI_DEVICE

/**
 * Atari ONLY
 * ----------
 * To enable this device is mandatory to follow the PBI device initialization

ZP:		equ $A0

buffer:
	.db	'SPI65 data interface', 0x00

init:
		lda #$80
		sta $D1FF
		; Now the device is ready and the D5xx (nCCTL) address space is ready
		; to be used
busy:
		lda $D500	;--> read from SPI Status Register
		and #$20
		beq busy
		rts

txcomplete:
		lda $D500
		and #$80
		beq txcomplete
		rts

; Now the SPI is ready to be used
		lda #3
		sta $D501	; setup CPOL and CPHA
		lda #02
		sta $D502	; store DIV8 CLK divisor
		lda #1
		sta $D503	; setup SLAVE #1 SPI_SEL0

		lda #buffer%256
		sta ZP
		lda #buffer%256
		sta ZP+1
		ldx #0

start:
		; Get the first character from buffer
		lda $(ZP),x
		bnz spiwrite
		rts		; EXIT

spiwrite:
		sta $D500
		jsr txcomplete	; wait completion
		inx
		jmp start

-----------------------------------------------------------------------------

In C:

void init(void)
{
	uint8_t * ptr = 0xD1FF;
	*(ptr) = 0x80;
}

void busy(void)
{
	uint8_t status;
	for (;;)
	{
		status = *(0xD500);
		if (status & 0x20)
			continue;
		else
			break;
	}
}

void txcomplete(void)
{
	uint8_t status;
	for (;;)
	{
		status = *(0xD500);
		if (status & 0x80)
			continue;
		else
			break;
	}
}

void main(void)
{
	unsigned char[] = "SPI65 data interface";
	int x;
	uint8_t * reg;

	init();

	reg = 0xD500;
	*(reg + 1) = 3; // setup CPOL and CPHA
	*(reg + 2) = 2; // store DIV8 CLK divisor
	*(reg + 3) = 1; // setup SLAVE #1 SPI_SEL0

	for (x = 0; x < strlen(char); x++)
	{
		*(reg) = char[x];
		txcomplete();
	}
	// EXIT
}



**/
// STATUS & CONTROL REGISTERS
#define TC   (1 << 7) //$80
#define IER  (1 << 6) //$40
#define BSY  (1 << 5) //$20
#define FRX  (1 << 4) //$10
#define TMO  (1 << 3) //$08
#define ECE  (1 << 2) //$04
#define CPOL (1 << 1) //$02
#define CPHA (1 << 0) //$01

#define spi_write() LL_SPI_TransmitData8(SPI1, SPI_DATA_OUT);
#define spi_read()  LL_SPI_ReceiveData8(SPI1);

// SCLK DIVISOR REGISTER
/**
 * bit 0-2 as divisor (from 0 (CLK/2) to 7 (CLK/8)
 **/
static int debuglevel = DBG_INFO;

void SystemClock_Config(void);
static void gpio_init(void);
static void usart_config(int baudrate);

static LL_SPI_InitTypeDef SPI_InitStruct = {0};

/**
  * @brief System Clock Configuration
  * @retval None
  */
void SystemClock_Config(void)
{
	LL_FLASH_SetLatency(LL_FLASH_LATENCY_5);

	if(LL_FLASH_GetLatency() != LL_FLASH_LATENCY_5)
	{
		Error_Handler("SystemClock_Config");
	}
	LL_PWR_SetRegulVoltageScaling(LL_PWR_REGU_VOLTAGE_SCALE1);
	LL_PWR_EnableOverDriveMode();
	LL_RCC_HSE_EnableBypass();
	LL_RCC_HSE_Enable();

	/* Wait till HSE is ready */
	while(LL_RCC_HSE_IsReady() != 1)
		;;

	LL_RCC_PLL_ConfigDomain_SYS(LL_RCC_PLLSOURCE_HSE, LL_RCC_PLLM_DIV_4, 180, LL_RCC_PLLP_DIV_2);
	LL_RCC_PLL_Enable();

	/* Wait till PLL is ready */
	while(LL_RCC_PLL_IsReady() != 1)
		;;

	LL_RCC_SetAHBPrescaler(LL_RCC_SYSCLK_DIV_1);
	LL_RCC_SetAPB1Prescaler(LL_RCC_APB1_DIV_4);
	LL_RCC_SetAPB2Prescaler(LL_RCC_APB2_DIV_2);
	LL_RCC_SetSysClkSource(LL_RCC_SYS_CLKSOURCE_PLL);

	/* Wait till System clock is ready */
	while(LL_RCC_GetSysClkSource() != LL_RCC_SYS_CLKSOURCE_STATUS_PLL)
		;;

	/* We are running @ 180Mhz */
	LL_Init1msTick(180000000);
	LL_SYSTICK_SetClkSource(LL_SYSTICK_CLKSOURCE_HCLK);
	LL_SetSystemCoreClock(180000000);
	LL_RCC_SetTIMPrescaler(LL_RCC_TIM_PRESCALER_TWICE);
}

/**
  * @brief USART1 Initialization Function
  * @param None
  * @retval None
  */
static void usart_config(int baudrate)
{
	LL_USART_InitTypeDef USART_InitStruct = {0};

	LL_GPIO_InitTypeDef GPIO_InitStruct = {0};

	/* Peripheral clock enable */
	LL_APB2_GRP1_EnableClock(LL_APB2_GRP1_PERIPH_USART1);

	LL_AHB1_GRP1_EnableClock(LL_AHB1_GRP1_PERIPH_GPIOA);
	/**USART1 GPIO Configuration
	PA9   ------> USART1_TX
	PA10   ------> USART1_RX
	*/
	GPIO_InitStruct.Pin = DEBUG_TX_Pin|DEBUG_RX_Pin;
	GPIO_InitStruct.Mode = LL_GPIO_MODE_ALTERNATE;
	GPIO_InitStruct.Speed = LL_GPIO_SPEED_FREQ_VERY_HIGH;
	GPIO_InitStruct.OutputType = LL_GPIO_OUTPUT_PUSHPULL;
	GPIO_InitStruct.Pull = LL_GPIO_PULL_UP;
	GPIO_InitStruct.Alternate = LL_GPIO_AF_7;
	LL_GPIO_Init(GPIOA, &GPIO_InitStruct);

	USART_InitStruct.BaudRate = 115200;
	USART_InitStruct.DataWidth = LL_USART_DATAWIDTH_8B;
	USART_InitStruct.StopBits = LL_USART_STOPBITS_1;
	USART_InitStruct.Parity = LL_USART_PARITY_NONE;
	USART_InitStruct.TransferDirection = LL_USART_DIRECTION_TX_RX;
	USART_InitStruct.HardwareFlowControl = LL_USART_HWCONTROL_NONE;
	USART_InitStruct.OverSampling = LL_USART_OVERSAMPLING_16;
	LL_USART_Init(USART1, &USART_InitStruct);
	LL_USART_ConfigAsyncMode(USART1);
	LL_USART_Enable(USART1);
}

/**
  * @brief GPIO Initialization Function
  * @param None
  * @retval None
  */
static void gpio_init(void)
{
	LL_GPIO_InitTypeDef GPIO_InitStruct = {0};

	/* GPIO Ports Clock Enable */
	LL_AHB1_GRP1_EnableClock(LL_AHB1_GRP1_PERIPH_GPIOE);
	LL_AHB1_GRP1_EnableClock(LL_AHB1_GRP1_PERIPH_GPIOI);
	LL_AHB1_GRP1_EnableClock(LL_AHB1_GRP1_PERIPH_GPIOC);
	LL_AHB1_GRP1_EnableClock(LL_AHB1_GRP1_PERIPH_GPIOF);
	LL_AHB1_GRP1_EnableClock(LL_AHB1_GRP1_PERIPH_GPIOH);
	LL_AHB1_GRP1_EnableClock(LL_AHB1_GRP1_PERIPH_GPIOA);
	LL_AHB1_GRP1_EnableClock(LL_AHB1_GRP1_PERIPH_GPIOB);
	LL_AHB1_GRP1_EnableClock(LL_AHB1_GRP1_PERIPH_GPIOG);
	LL_AHB1_GRP1_EnableClock(LL_AHB1_GRP1_PERIPH_GPIOD);

	/* Low level by default */
	LL_GPIO_ResetOutputPin(GPIOB, LED_Pin | PB6_Pin | PB9_Pin);

	/* ------------------------
	 * CONTROL SIGNALS TO 6502
	 * ------------------------
	 * High level (not active) by default */
	LL_GPIO_SetOutputPin(GPIOB,
		m_RST_Pin  | m_RD5_Pin   | m_IRQ_Pin  | m_RD4_Pin | m_EXSEL_Pin |
		m_HALT_Pin | m_MPD_Pin);

	/* -------------------------
	 * CONTROL SIGNAL FROM 6502
	 * -------------------------
	 * mPHI2 = PHASE 2 CLOCK OUTPUT FROM 6502
	 * mS5   = 6502 ACCESSING TO $A000-$BFFF (LOW ACTIVE)
	 * mS4   = 6502 ACCESSING TO $8000-$9FFF (LOW ACTIVE)
	 * mD1XX = 6502 ACCESSING TO PBI $D100-$D1FF (LOW ACTIVE)
	 * mCCTL = 6502 ACCESSING TO $D500-$D5FF/$DE00-$DEFF/$DF00-$DFFF (LOW ACTIVE)
	 * mRW   = 6502 R/_W SIGNAL (Read = 1, Write = 0)
	 */
	GPIO_InitStruct.Pin =
		m_PHI2_Pin | m_S5_Pin   | m_S4_Pin |
		m_D1XX_Pin | m_CCTL_Pin | m_RW_Pin;

	GPIO_InitStruct.Mode = LL_GPIO_MODE_INPUT;
	GPIO_InitStruct.Pull = LL_GPIO_PULL_NO;
	LL_GPIO_Init(GPIOI, &GPIO_InitStruct);

	/* ----------------------------
	 * ADDRESS BUS FROM 6502 - 16BIT
	 * ---------------------------- */
	GPIO_InitStruct.Pin =
		m_A0_Pin  | m_A1_Pin  | m_A2_Pin  | m_A3_Pin  |
		m_A4_Pin  | m_A5_Pin  | m_A6_Pin  | m_A7_Pin  |
		m_A8_Pin  | m_A9_Pin  | m_A10_Pin | m_A11_Pin |
		m_A12_Pin | m_A13_Pin | m_A14_Pin | m_A15_Pin;

	GPIO_InitStruct.Mode = LL_GPIO_MODE_INPUT;
	GPIO_InitStruct.Pull = LL_GPIO_PULL_NO;
	LL_GPIO_Init(GPIOC, &GPIO_InitStruct);

	/* ----------------------
	 * DATA BUS FROM/TO 6502
	 * ---------------------- */
	GPIO_InitStruct.Pin =
		m_D0_Pin | m_D1_Pin | m_D2_Pin | m_D3_Pin |
		m_D4_Pin | m_D5_Pin | m_D6_Pin | m_D7_Pin;
	GPIO_InitStruct.Mode = LL_GPIO_MODE_INPUT;
	GPIO_InitStruct.Pull = LL_GPIO_PULL_NO;
	LL_GPIO_Init(GPIOG, &GPIO_InitStruct);

	/* ------------------------
	 * CONTROL SIGNALS TO 6502
	 * ------------------------
	 * mRST   = RESET 6502 (LOW ACTIVE)
	 * mRD5   = Accessing Cartridge Area $A000-$BFFF (LOW ACTIVE)
	 * mRD4   = Accessing Cartridge Area $8000-$9FFF (LOW ACTIVE)
	 * mIRQ   = External IRQ requested TBD  (LOW ACTIVE)
	 * mEXSEL = Internal RAM Access Disable (LOW ACTIVE)
	 * mHALT  = HALT 6502 (LOW ACTIVE DMA STEAL CYCLES)
	 * mMPD   = INTERNAL MATH PACK ROM DISABLE ($D800-$DFFF 2K)
	 */
	GPIO_InitStruct.Pin =
		LED_Pin    | m_RST_Pin   | m_RD5_Pin   | m_IRQ_Pin  |
		m_RD4_Pin  | m_EXSEL_Pin | m_HALT_Pin  | m_MPD_Pin;

	/* Miscellaneous pins for STM32F4 bootup */
	GPIO_InitStruct.Pin |= PB6_Pin | PB9_Pin;

	GPIO_InitStruct.Mode = LL_GPIO_MODE_OUTPUT;
	GPIO_InitStruct.Speed = LL_GPIO_SPEED_FREQ_VERY_HIGH;
	GPIO_InitStruct.OutputType = LL_GPIO_OUTPUT_PUSHPULL;
	GPIO_InitStruct.Pull = LL_GPIO_PULL_NO;
	LL_GPIO_Init(GPIOB, &GPIO_InitStruct);

	/* SPI Chip SELECT Config */
	GPIO_InitStruct.Pin =
		SPI_SEL0_GPIO_Pin | SPI_SEL1_GPIO_Pin |
		SPI_SEL2_GPIO_Pin | SPI_SEL3_GPIO_Pin;
	GPIO_InitStruct.Mode = LL_GPIO_MODE_OUTPUT;
	GPIO_InitStruct.Speed = LL_GPIO_SPEED_FREQ_VERY_HIGH;
	GPIO_InitStruct.OutputType = LL_GPIO_OUTPUT_PUSHPULL;
	GPIO_InitStruct.Pull = LL_GPIO_PULL_UP; /* All devices start deselected */
	LL_GPIO_Init(SPI_SEL0_GPIO_Port, &GPIO_InitStruct);
}


static void spi_core_config(LL_SPI_InitTypeDef *spi, uint32_t prescaler, uint32_t cpol, uint32_t cpha)
{
	if (spi != NULL)
	{
		spi->BaudRate = prescaler;
		spi->ClockPolarity = cpol;
		spi->ClockPhase = cpha;
		LL_SPI_Init(SPI1, spi);
		LL_SPI_SetStandard(SPI1, LL_SPI_PROTOCOL_MOTOROLA);
	}
}

static void spi_init(void)
{
	LL_GPIO_InitTypeDef GPIO_InitStruct;

	/* Peripherl Clock enable */
	LL_APB2_GRP1_EnableClock(LL_APB2_GRP1_PERIPH_SPI1);

	/* SPI1 GPIO Config */
	GPIO_InitStruct.Pin = SPI1_MISO_Pin | SPI1_MOSI_Pin | SPI1_SCK_Pin;
	GPIO_InitStruct.Mode = LL_GPIO_MODE_ALTERNATE;
	GPIO_InitStruct.Speed = LL_GPIO_SPEED_FREQ_VERY_HIGH;
	GPIO_InitStruct.OutputType = LL_GPIO_OUTPUT_PUSHPULL;
	GPIO_InitStruct.Pull = LL_GPIO_PULL_NO;
	GPIO_InitStruct.Alternate = LL_GPIO_AF_5;
	LL_GPIO_Init(SPI1_MISO_Port, &GPIO_InitStruct);

	/* SPI Core Config */
	SPI_InitStruct.TransferDirection = LL_SPI_FULL_DUPLEX;
	SPI_InitStruct.Mode = LL_SPI_MODE_MASTER;
	SPI_InitStruct.DataWidth = LL_SPI_DATAWIDTH_8BIT;
	SPI_InitStruct.NSS = LL_SPI_NSS_SOFT;
	SPI_InitStruct.BitOrder = LL_SPI_LSB_FIRST;
	SPI_InitStruct.CRCCalculation = LL_SPI_CRCCALCULATION_DISABLE;
	SPI_InitStruct.CRCPoly = 7;

	spi_core_config(&SPI_InitStruct, LL_SPI_BAUDRATEPRESCALER_DIV8, LL_SPI_POLARITY_LOW, LL_SPI_PHASE_1EDGE);
}

static void banner(void)
{
	DBG_I("SPI65 SOFT CORE BOARD\r\n");
	DBG_I("(C) RetroBit Lab 2019/2020 written by Gianluca Renzi <icjtqr@gmail.com>\r\n");
}

/**
  * @brief  Theory of operation:
  *
  * 6502 Computers when accessing to specific address ($D500-$D$D5FF or
  * $DE00-$DEFF, or $DF00-$DFFF) is trying to talk with a SPI device
  *
  * This software intercept the memory access to those address to configure
  * the SPI scheme with a compatible mode, and enables the SPI Hardware
  * in the STM32 Core.
  *
  *
  * @retval int
  */


static inline void spi_setup_ctrl(void)
{
	volatile int cpol = (SPI_CONTROL_REGISTER & CPOL) >> 1;
	volatile int cpha = (SPI_CONTROL_REGISTER & CPHA) >> 0;
	volatile uint8_t reg = SPI_STATUS_REGISTER;
	spi_cpha = cpha;
	spi_cpol = cpol;
	spi_core_config(&SPI_InitStruct, spi_prescaler,
		cpol == 1 ? LL_SPI_POLARITY_LOW : LL_SPI_POLARITY_HIGH,
		cpha == 0 ? LL_SPI_PHASE_1EDGE : LL_SPI_PHASE_2EDGE);

	if (cpol) reg |= (CPOL); else reg &= ~(CPOL);
	if (cpha) reg |= (CPHA); else reg &= ~(CPHA);

	SPI_STATUS_REGISTER |= reg;
}

static inline void spi_setup_clock(void)
{
	volatile int clock = (SPI_CLK_DIVISOR_REGISTER & 0x07);
	spi_prescaler = clock;
	switch(clock)
	{
		case 0:
			spi_core_config(&SPI_InitStruct, LL_SPI_BAUDRATEPRESCALER_DIV2,
				spi_cpol, spi_cpha);
		case 1:
			spi_core_config(&SPI_InitStruct, LL_SPI_BAUDRATEPRESCALER_DIV4,
				spi_cpol, spi_cpha);
		case 2:
			spi_core_config(&SPI_InitStruct, LL_SPI_BAUDRATEPRESCALER_DIV8,
				spi_cpol, spi_cpha);
		case 3:
			spi_core_config(&SPI_InitStruct, LL_SPI_BAUDRATEPRESCALER_DIV16,
				spi_cpol, spi_cpha);
		case 4:
			spi_core_config(&SPI_InitStruct, LL_SPI_BAUDRATEPRESCALER_DIV32,
				spi_cpol, spi_cpha);
		case 5:
			spi_core_config(&SPI_InitStruct, LL_SPI_BAUDRATEPRESCALER_DIV64,
				spi_cpol, spi_cpha);
		case 6:
			spi_core_config(&SPI_InitStruct, LL_SPI_BAUDRATEPRESCALER_DIV128,
				spi_cpol, spi_cpha);
		case 7:
			spi_core_config(&SPI_InitStruct, LL_SPI_BAUDRATEPRESCALER_DIV256,
				spi_cpol, spi_cpha);
		default:
			break;
	}
}

static inline void spi_setup_slave(void)
{
	volatile int slave = (SPI_SLAVE_SELECT_REGISTER & 0x0F);
	volatile uint8_t slaves[] = { 0, 1, 2, 4, 8 };
	volatile int i;
	volatile uint8_t reg = SPI_SLAVE_SELECT_REGISTER;
	volatile int found = 0;

	/* Only one slave at time! 0 (no sel), 1, 2, 4, 8 are valid values! */
	for (i = 0; i < 5; i++)
	{
		if (slave == slaves[i]) { found = 1; break; }
	}

	if (found)
	{
		if (slave == 0)
			return;
		spi_csel = slave;
		reg &= ~(0x0F);
		reg |= slave;
		SPI_SLAVE_SELECT(slave);
	}
	else
	{
		/* Invalid SLAVE number */
		reg &= ~(0x0F);
	}
	SPI_SLAVE_SELECT_REGISTER = reg;
}

int main(void)
{
	uint16_t addr;
	uint8_t data;
	uint8_t c;

	_write_ready(SYSCALL_NOTREADY); // printf is not functional here

	/* Reset of all peripherals, Initializes the Flash interface and the Systick. */
	HAL_Init();
	/* Configure the system clock */
	SystemClock_Config();

	/* Initialize all configured peripherals */
	gpio_init();

	/* keep 6502 CPU on RESET as soon as possible */
	CPU_RESET_ASSERT;

	spi_init();
	LL_SPI_Disable(SPI1);

	/* Configure USART1 for 115200 8N1 */
	usart_config(115200);
	_write_ready(SYSCALL_READY); // printf is functional from now on...

	GREEN_LED_ON; // Means board is alive!

	// Start READING FROM DATABUS!
	SET_DATA_MODE_IN

	// Not needed if using FreeRTOS!
	__disable_irq();

	banner();

	mdelay(500);

	GREEN_LED_OFF; // Now starts with led off. Only accessing external RAM will blink!

#ifndef ATARI_PBI_DEVICE
	SPI_ENABLED = 1;
#endif

	/* Now it's time to put 6502 CPU OUT OF RESET */
	CPU_RESET_DEASSERT;

	while (1)
	{

		// wait for phi2 high
		// Wait for a valid chip select pin
		while (!((c = CONTROL_IN) & PHI2))
			;

		if (!(c & CCTL))
		{
			if (SPI_ENABLED)
			{
				// Check for address only if there is a valid state of the PHI2
				// on the bus!
				addr = ADDR_IN & 0x03; // we have only 4 address register space available

				// 6502 CPU Needs to WRITE Data?
				if (!(c & RW))
				{
					// Now READs the data to be written
					data = DATA_IN;
					// read the data bus on falling edge of phi2
					while (CONTROL_IN & PHI2)
						data = DATA_IN;

					switch (addr)
					{
						case 0x00:
							// SPI DATA OUT
							SPI_DATA_OUT = data;
							LL_SPI_Enable(SPI1);
							spi_write();
							break;
						case 0x01:
							// SPI CTRL REGISTER
							SPI_CONTROL_REGISTER = data;
							LL_SPI_Disable(SPI1);
							spi_setup_ctrl();
							break;
						case 0x02:
							// SPI CLOCK DIVISOR
							SPI_CLK_DIVISOR_REGISTER = data;
							LL_SPI_Disable(SPI1);
							spi_setup_clock();
							break;
						case 0x03:
							// SPI SLAVE SELECT
							SPI_SLAVE_SELECT_REGISTER = data;
							LL_SPI_Disable(SPI1);
							spi_setup_slave();
							break;
					}
				}
				else
				{
					// 6502 CPU Needs to READ Data
					SET_DATA_MODE_OUT

					switch (addr)
					{
						case 0x00:
							// SPI DATA IN
							LL_SPI_Enable(SPI1);
							DATA_OUT = spi_read();
							// This clear the TC bit in the STATUS REGISTER
							SPI_STATUS_REGISTER &= ~ TC;
							break;
						case 0x01:
							// SPI STATUS REGISTER
							DATA_OUT = SPI_STATUS_REGISTER;
							break;
						case 0x02:
							// SPI CLOCK DIVISOR
							DATA_OUT = SPI_CLK_DIVISOR_REGISTER;
							break;
						case 0x03:
							// SPI SLAVE SELECT
							DATA_OUT = SPI_SLAVE_SELECT_REGISTER;
							break;
					}

					// wait for phi2 low
					while (CONTROL_IN & PHI2)
						;
					SET_DATA_MODE_IN
				}
			}
		}

#ifdef ATARI_PBI_DEVICE
#warning "ATARI ONLY SETUP! PBI DEVICE"
		if (!(c & D1XX))
		{
			addr = ADDR_IN & 0xFF; // Check D1FF
			if (addr == 0xFF)
			{
				// 6502 CPU Needs to WRITE Data?
				if (!(c & RW))
				{
					// Now READs the data to be written
					data = DATA_IN;
					// read the data bus on falling edge of phi2
					while (CONTROL_IN & PHI2)
						data = DATA_IN;
					switch (data)
					{
						case 0x80:
							SPI_ENABLED = 1; // Now our device is ready
							GREEN_LED_ON;
							break;
						case 0x00:
							SPI_ENABLED = 0; // Disable our device
							GREEN_LED_OFF;
							break;
						default:
							break; // Not for us
					}
				}
			}
		}
#endif
	}

	return 0; // NEVERREACHED
}

/**
  * @brief  This function is executed in case of error occurrence.
  * @retval None
  */
void Error_Handler(const char *c)
{
	DBG_E("%s\n\r", c);
	for (;;)
		;;
}

#ifdef  USE_FULL_ASSERT
/**
  * @brief  Reports the name of the source file and the source line number
  *         where the assert_param error has occurred.
  * @param  file: pointer to the source file name
  * @param  line: assert_param error line source number
  * @retval None
  */
void assert_failed(uint8_t *file, uint32_t line)
{
	/* User can add his own implementation to report the file name and line number,
	 tex: printf("Wrong parameters value: file %s on line %d\r\n", file, line) */
	DBG_E("Error! Wrong parameters value: file %s on line %d\r\n", file, line);
	for (;;)
		;;
}
#endif /* USE_FULL_ASSERT */

/************************ (C) COPYRIGHT STMicroelectronics *****END OF FILE****/

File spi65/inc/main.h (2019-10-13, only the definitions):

#define m_A15_Pin LL_GPIO_PIN_15
#define m_A15_GPIO_Port GPIOC
#define m_A14_Pin LL_GPIO_PIN_14
#define m_A14_GPIO_Port GPIOC
#define m_A13_Pin LL_GPIO_PIN_13
#define m_A13_GPIO_Port GPIOC
#define m_A12_Pin LL_GPIO_PIN_12
#define m_A12_GPIO_Port GPIOC
#define m_A11_Pin LL_GPIO_PIN_11
#define m_A11_GPIO_Port GPIOC
#define m_A10_Pin LL_GPIO_PIN_10
#define m_A10_GPIO_Port GPIOC
#define m_A9_Pin LL_GPIO_PIN_9
#define m_A9_GPIO_Port GPIOC
#define m_A8_Pin LL_GPIO_PIN_8
#define m_A8_GPIO_Port GPIOC
#define m_A7_Pin LL_GPIO_PIN_7
#define m_A7_GPIO_Port GPIOC
#define m_A6_Pin LL_GPIO_PIN_6
#define m_A6_GPIO_Port GPIOC
#define m_A5_Pin LL_GPIO_PIN_5
#define m_A5_GPIO_Port GPIOC
#define m_A4_Pin LL_GPIO_PIN_4
#define m_A4_GPIO_Port GPIOC
#define m_A3_Pin LL_GPIO_PIN_3
#define m_A3_GPIO_Port GPIOC
#define m_A2_Pin LL_GPIO_PIN_2
#define m_A2_GPIO_Port GPIOC
#define m_A1_Pin LL_GPIO_PIN_1
#define m_A1_GPIO_Port GPIOC
#define m_A0_Pin LL_GPIO_PIN_0
#define m_A0_GPIO_Port GPIOC
#define m_D0_Pin LL_GPIO_PIN_0
#define m_D0_GPIO_Port GPIOG
#define m_D1_Pin LL_GPIO_PIN_1
#define m_D1_GPIO_Port GPIOG
#define m_D2_Pin LL_GPIO_PIN_2
#define m_D2_GPIO_Port GPIOG
#define m_D3_Pin LL_GPIO_PIN_3
#define m_D3_GPIO_Port GPIOG
#define m_D4_Pin LL_GPIO_PIN_4
#define m_D4_GPIO_Port GPIOG
#define m_D5_Pin LL_GPIO_PIN_5
#define m_D5_GPIO_Port GPIOG
#define m_D6_Pin LL_GPIO_PIN_6
#define m_D6_GPIO_Port GPIOG
#define m_D7_Pin LL_GPIO_PIN_7
#define m_D7_GPIO_Port GPIOG
#define LED_Pin LL_GPIO_PIN_0
#define LED_GPIO_Port GPIOB
#define m_RST_Pin LL_GPIO_PIN_1
#define m_RST_GPIO_Port GPIOB
#define m_RD5_Pin LL_GPIO_PIN_2
#define m_RD5_GPIO_Port GPIOB
#define m_RD4_Pin LL_GPIO_PIN_4
#define m_RD4_GPIO_Port GPIOB
#define m_EXSEL_Pin LL_GPIO_PIN_5
#define m_EXSEL_GPIO_Port GPIOB
#define PB6_Pin LL_GPIO_PIN_6
#define PB6_GPIO_Port GPIOB
#define m_HALT_Pin LL_GPIO_PIN_7
#define m_HALT_GPIO_Port GPIOB
#define m_MPD_Pin LL_GPIO_PIN_8
#define m_MPD_GPIO_Port GPIOB
#define PB9_Pin LL_GPIO_PIN_9
#define PB9_GPIO_Port GPIOB
#define m_IRQ_Pin LL_GPIO_PIN_10
#define m_IRQ_GPIO_Port GPIOB
#define m_PHI2_Pin LL_GPIO_PIN_0
#define m_PHI2_GPIO_Port GPIOI
#define m_S5_Pin LL_GPIO_PIN_1
#define m_S5_GPIO_Port GPIOI
#define m_S4_Pin LL_GPIO_PIN_2
#define m_S4_GPIO_Port GPIOI
#define m_D1XX_Pin LL_GPIO_PIN_3
#define m_D1XX_GPIO_Port GPIOI
#define m_CCTL_Pin LL_GPIO_PIN_4
#define m_CCTL_GPIO_Port GPIOI
#define m_RW_Pin LL_GPIO_PIN_5
#define m_RW_GPIO_Port GPIOI
#define m_IO1_Pin LL_GPIO_PIN_9
#define m_IO1_GPIO_Port GPIOI
#define m_IO2_Pin LL_GPIO_PIN_10
#define m_IO2_GPIO_Port GPIOI
#define DEBUG_TX_Pin LL_GPIO_PIN_9
#define DEBUG_TX_GPIO_Port GPIOA
#define DEBUG_RX_Pin LL_GPIO_PIN_10
#define DEBUG_RX_GPIO_Port GPIOA
#define CONF0_Pin LL_GPIO_PIN_6
#define CONF0_GPIO_Port GPIOI
#define CONF1_Pin LL_GPIO_PIN_7
#define CONF1_GPIO_Port GPIOI
#define CONF2_Pin LL_GPIO_PIN_8
#define CONF2_GPIO_Port GPIOI
#define SPI1_MISO_Port GPIOA
#define SPI1_MISO_Pin LL_GPIO_PIN_6
#define SPI1_SCK_Port GPIOA
#define SPI1_SCK_Pin LL_GPIO_PIN_5
#define SPI1_MOSI_Port GPIOA
#define SPI1_MOSI_Pin LL_GPIO_PIN_7
#define SPI_SEL0_GPIO_Pin  LL_GPIO_PIN_0
#define SPI_SEL0_GPIO_Port GPIOA
#define SPI_SEL1_GPIO_Pin  LL_GPIO_PIN_1
#define SPI_SEL1_GPIO_Port GPIOA
#define SPI_SEL2_GPIO_Pin  LL_GPIO_PIN_2
#define SPI_SEL2_GPIO_Port GPIOA
#define SPI_SEL3_GPIO_Pin  LL_GPIO_PIN_3
#define SPI_SEL3_GPIO_Port GPIOA

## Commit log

2019-10-13 First Import
    [mcu_memory.sch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]
2019-10-14 Corrected pinout of lateral IDC 40 pin. Moved other bits to another port
    [mcu_memory.sch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]
2019-10-14 - Corrected the PBI Device # read on address bus (was 0x0F instead of 0xFF) - SPI_ENABLED is invoked __before__ running the main loop if __no__ ATARI_PBI_DEVICE is defined
    [main.c]
2019-10-19 Rerouting with length match
    [stduinof429-B.Cu.gbl, stduinof429-B.Mask.gbs, stduinof429-B.Paste.gbp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]
2019-11-01 Updated. Ready to be ordered
    [stduinof429-digikey.ods]
2019-11-02 Modified using the Digikey codes
    [stduinof429-digikey.ods]
2019-11-25 Added BillOfMaterial from Digikey in XLSX format
    [stduinof429-digikey.xlsx]
2019-11-25 Better layout
    [stduinof429-digikey.ods]
2020-05-23 Porting from Kicad 4 to Kicad 5
    [mcu_memory-2020-05-23-11-07-53.sch, stduinof429-2020-05-23-11-07-53.sch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]
2021-03-22 Removed. Not needed anymore
    [mcu_memory-2020-05-23-11-07-53.sch, stduinof429-2020-05-23-11-07-53.sch]
2021-03-22 Added without the packages/kicad folder needed. All stuff is now on kicad sources and RetroBitLab Library
    [mcu_memory.sch, stduinof429.kicad_pcb, stduinof429.sch]
2021-03-22 Modified for Kicad 5.1.9
    [stduinof429-Margin.gbr, stduinof429-NPTH.drl, stduinof429-PTH.drl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]
2021-03-25 Created for rescue :-(
    [mcu_memory.sch, stduinof429.kicad_pcb, stduinof429.sch]

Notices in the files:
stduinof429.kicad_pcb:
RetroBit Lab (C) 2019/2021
